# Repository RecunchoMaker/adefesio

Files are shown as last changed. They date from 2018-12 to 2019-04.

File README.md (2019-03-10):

# adefesio

**adefesio** intentará ser un pequeno robot para iniciarse na competición da resolución de
de labirintos. Está baseado en componentes de baixo custe (arduino, motores micrometal...)
e polo tanto a intención do proxecto non é facer un robot competitivo, senón explorar
e investigar os desfíos de programación que aparecen nesta competición.

## making off

En [Adefesio blog](https://recunchomaker.github.io/adefesio/) estamos facendo un
blog co progreso do proxecto.

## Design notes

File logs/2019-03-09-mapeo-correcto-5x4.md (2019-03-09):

GO!
leds:214	0	-1	289	
* accion: dist:0.09 acel= 1.00 vmax=0.20 vfin=0.20 deceleracion=1.00 pasos_hasta_dec=236 pasos_obj=236 r=99999.00
leds:249	1	0	174	
cambio a casilla 15
Orientacion 0
+-----+-----+-----+-----+
|   0     1     2     3 | 
|                       |     
+     +     +     +     +
|   5     6     7     8 | 
|                       |     
+     +     +     +     +
|  10    11    12    13 | 
|                       |     
+     +     +     +     +
|  15 |  16    17    18 | 
|   A |                 |     
+     +     +     +     +
|  20 |  21    22    23 | 
|     |                 |     
+-----+-----+-----+-----+

continuo - leds enfrente: 0/1
* accion: dist:0.18 acel= 1.00 vmax=0.20 vfin=0.20 deceleracion=1.00 pasos_hasta_dec=472 pasos_obj=472 r=99999.00
sinc pared derecha
leds:135	0	0	0	
cambio a casilla 10
Orientacion 0
+-----+-----+-----+-----+
|   0     1     2     3 | 
|                       |     
+     +     +     +     +
|   5     6     7     8 | 
|                       |     
+     +     +     +     +
|  10    11    12    13 | 
|   A                   |     
+     +     +     +     +
|  15 |  16    17    18 | 
|     |                 |     
+     +     +     +     +
|  20 |  21    22    23 | 
|     |                 |     
+-----+-----+-----+-----+

continuo - leds enfrente: 0/0
pp giro derecha
* accion: dist:0.09 acel= 1.00 vmax=0.20 vfin=0.10 deceleracion=0.80 pasos_hasta_dec=186 pasos_obj=236 r=99999.00
pausa pregiro
* accion: dist:0.00 acel= 0.00 vmax=0.00 vfin=0.00 deceleracion=0.00 pasos_hasta_dec=-2147483648 pasos_obj=0 r=0.20
leds:112	1	1	1	
giro derecha
* accion: dist:0.05 acel= 1.00 vmax=0.20 vfin=0.10 deceleracion=1.00 pasos_hasta_dec=92 pasos_obj=131 r=0.01
pausa inicial
* accion: dist:0.00 acel= 0.00 vmax=0.00 vfin=0.00 deceleracion=0.00 pasos_hasta_dec=-2147483648 pasos_obj=0 r=0.20
Orientacion 1
+-----+-----+-----+-----+
|   0     1     2     3 | 
|                       |     
+     +     +     +     +
|   5     6     7     8 | 
|                       |     
+     +     +     +     +
|  10    11    12    13 | 
|   >                   |     
+     +     +     +     +
|  15 |  16    17    18 | 
|     |                 |     
+     +     +     +     +
|  20 |  21    22    23 | 
|     |                 |     
+-----+-----+-----+-----+

* accion: dist:0.09 acel= 1.00 vmax=0.20 vfin=0.20 deceleracion=1.00 pasos_hasta_dec=236 pasos_obj=236 r=99999.00
leds:160	0	0	222	
cambio a casilla 11
Orientacion 1
+-----+-----+-----+-----+
|   0     1     2     3 | 
|                       |     
+     +     +     +     +
|   5     6     7     8 | 
|                       |     
+     +-----+     +     +
|  10    11    12    13 | 
|         >             |     
+     +-----+     +     +
|  15 |  16    17    18 | 
|     |                 |     
+     +     +     +     +
|  20 |  21    22    23 | 
|     |                 |     
+-----+-----+-----+-----+

continuo - leds enfrente: 0/0
* accion: dist:0.18 acel= 1.00 vmax=0.20 vfin=0.20 deceleracion=1.00 pasos_hasta_dec=472 pasos_obj=472 r=99999.00
sinc pared derecha
leds:134	1	1	0	
cambio a casilla 12
Orientacion 1
+-----+-----+-----+-----+
|   0     1     2     3 | 
|                       |     
+     +     +     +     +
|   5     6     7     8 | 
|                       |     
+     +-----+-----+     +
|  10    11    12    13 | 
|               >       |     
+     +-----+     +     +
|  15 |  16    17    18 | 
|     |                 |     
+     +     +     +     +
|  20 |  21    22    23 | 
|     |                 |     
+-----+-----+-----+-----+

continuo - leds enfrente: 1/1
pp giro derecha
* accion: dist:0.09 acel= 1.00 vmax=0.20 vfin=0.10 deceleracion=0.80 pasos_hasta_dec=186 pasos_obj=236 r=99999.00
pausa pregiro
* accion: dist:0.00 acel= 0.00 vmax=0.00 vfin=0.00 deceleracion=0.00 pasos_hasta_dec=-2147483648 pasos_obj=0 r=0.20
leds:138	5	3	2	
giro derecha
* accion: dist:0.05 acel= 1.00 vmax=0.20 vfin=0.10 deceleracion=1.00 pasos_hasta_dec=92 pasos_obj=131 r=0.01
pausa inicial
* accion: dist:0.00 acel= 0.00 vmax=0.00 vfin=0.00 deceleracion=0.00 pasos_hasta_dec=-2147483648 pasos_obj=0 r=0.20
Orientacion 2
+-----+-----+-----+-----+
|   0     1     2     3 | 
|                       |     
+     +     +     +     +
|   5     6     7     8 | 
|                       |     
+     +-----+-----+     +
|  10    11    12    13 | 
|               V       |     
+     +-----+     +     +
|  15 |  16    17    18 | 
|     |                 |     
+     +     +     +     +
|  20 |  21    22    23 | 
|     |                 |     
+-----+-----+-----+-----+

* accion: dist:0.09 acel= 1.00 vmax=0.20 vfin=0.20 deceleracion=1.00 pasos_hasta_dec=236 pasos_obj=236 r=99999.00
leds:212	1	1	247	
cambio a casilla 17
Orientacion 2
+-----+-----+-----+-----+
|   0     1     2     3 | 
|                       |     
+     +     +     +     +
|   5     6     7     8 | 
|                       |     
+     +-----+-----+     +
|  10    11    12    13 | 
|                       |     
+     +-----+     +     +
|  15 |  16 |  17 |  18 | 
|     |     |   V |     |     
+     +     +     +     +
|  20 |  21    22    23 | 
|     |                 |     
+-----+-----+-----+-----+

continuo - leds enfrente: 1/1
* accion: dist:0.18 acel= 1.00 vmax=0.20 vfin=0.20 deceleracion=1.00 pasos_hasta_dec=472 pasos_obj=472 r=99999.00
sinc pared derecha
leds:1	41	18	0	
cambio a casilla 22
Orientacion 2
+-----+-----+-----+-----+
|   0     1     2     3 | 
|                       |     
+     +     +     +     +
|   5     6     7     8 | 
|                       |     
+     +-----+-----+     +
|  10    11    12    13 | 
|                       |     
+     +-----+     +     +
|  15 |  16 |  17 |  18 | 
|     |     |     |     |     
+     +     +     +     +
|  20 |  21    22    23 | 
|     |         V       |     
+-----+-----+-----+-----+

continuo - leds enfrente: 18/41
pp giro derecha
* accion: dist:0.09 acel= 1.00 vmax=0.20 vfin=0.10 deceleracion=0.80 pasos_hasta_dec=186 pasos_obj=236 r=99999.00
chocamos! leds:
238/377, pasos objetivo =236 recorridos =186
pausa pregiro
* accion: dist:0.00 acel= 0.00 vmax=0.00 vfin=0.00 deceleracion=0.00 pasos_hasta_dec=-2147483648 pasos_obj=0 r=0.20
leds:1	377	238	1	
giro derecha
* accion: dist:0.05 acel= 1.00 vmax=0.20 vfin=0.10 deceleracion=1.00 pasos_hasta_dec=92 pasos_obj=131 r=0.01
pausa inicial
* accion: dist:0.00 acel= 0.00 vmax=0.00 vfin=0.00 deceleracion=0.00 pasos_hasta_dec=-2147483648 pasos_obj=0 r=0.20
Orientacion 3
+-----+-----+-----+-----+
|   0     1     2     3 | 
|                       |     
+     +     +     +     +
|   5     6     7     8 | 
|                       |     
+     +-----+-----+     +
|  10    11    12    13 | 
|                       |     
+     +-----+     +     +
|  15 |  16 |  17 |  18 | 
|     |     |     |     |     
+     +     +     +     +
|  20 |  21    22    23 | 
|     |         <       |     
+-----+-----+-----+-----+

* accion: dist:0.09 acel= 1.00 vmax=0.20 vfin=0.20 deceleracion=1.00 pasos_hasta_dec=236 pasos_obj=236 r=99999.00
leds:109	40	12	1	
cambio a casilla 21
Orientacion 3
+-----+-----+-----+-----+
|   0     1     2     3 | 
|                       |     
+     +     +     +     +
|   5     6     7     8 | 
|                       |     
+     +-----+-----+     +
|  10    11    12    13 | 
|                       |     
+     +-----+     +     +
|  15 |  16 |  17 |  18 | 
|     |     |     |     |     
+     +     +     +     +
|  20 |  21    22    23 | 
|     |   <             |     
+-----+-----+-----+-----+

continuo - leds enfrente: 12/40
pp giro derecha
* accion: dist:0.09 acel= 1.00 vmax=0.20 vfin=0.10 deceleracion=0.80 pasos_hasta_dec=186 pasos_obj=236 r=99999.00
chocamos! leds:
236/379, pasos objetivo =236 recorridos =190
pausa pregiro
* accion: dist:0.00 acel= 0.00 vmax=0.00 vfin=0.00 deceleracion=0.00 pasos_hasta_dec=-2147483648 pasos_obj=0 r=0.20
leds:100	379	236	1	
giro derecha
* accion: dist:0.05 acel= 1.00 vmax=0.20 vfin=0.10 deceleracion=1.00 pasos_hasta_dec=92 pasos_obj=131 r=0.01
pausa inicial
* accion: dist:0.00 acel= 0.00 vmax=0.00 vfin=0.00 deceleracion=0.00 pasos_hasta_dec=-2147483648 pasos_obj=0 r=0.20
Orientacion 0
+-----+-----+-----+-----+
|   0     1     2     3 | 
|                       |     
+     +     +     +     +
|   5     6     7     8 | 
|                       |     
+     +-----+-----+     +
|  10    11    12    13 | 
|                       |     
+     +-----+     +     +
|  15 |  16 |  17 |  18 | 
|     |     |     |     |     
+     +     +     +     +
|  20 |  21    22    23 | 
|     |   A             |     
+-----+-----+-----+-----+

* accion: dist:0.09 acel= 1.00 vmax=0.20 vfin=0.20 deceleracion=1.00 pasos_hasta_dec=236 pasos_obj=236 r=99999.00
leds:194	93	60	267	
cambio a casilla 16
Orientacion 0
+-----+-----+-----+-----+
|   0     1     2     3 | 
|                       |     
+     +     +     +     +
|   5     6     7     8 | 
|                       |     
+     +-----+-----+     +
|  10    11    12    13 | 
|                       |     
+     +-----+     +     +
|  15 |  16 |  17 |  18 | 
|     |   A |     |     |     
+     +     +     +     +
|  20 |  21    22    23 | 
|     |                 |     
+-----+-----+-----+-----+

continuo - leds enfrente: 60/93
callejon sin salida - paro para giro 180
* accion: dist:0.09 acel= 1.00 vmax=0.20 vfin=0.10 deceleracion=0.80 pasos_hasta_dec=186 pasos_obj=236 r=99999.00
chocamos! leds:
276/329, pasos objetivo =236 recorridos =107
pausa pregiro
* accion: dist:0.00 acel= 0.00 vmax=0.00 vfin=0.00 deceleracion=0.00 pasos_hasta_dec=-2147483648 pasos_obj=0 r=0.20
leds:224	329	276	229	
giro 180
* accion: dist:0.10 acel= 1.00 vmax=0.20 vfin=0.10 deceleracion=1.00 pasos_hasta_dec=223 pasos_obj=262 r=0.00
pausa inicial
* accion: dist:0.00 acel= 0.00 vmax=0.00 vfin=0.00 deceleracion=0.00 pasos_hasta_dec=-2147483648 pasos_obj=0 r=0.20
Orientacion 2
+-----+-----+-----+-----+
|   0     1     2     3 | 
|                       |     
+     +     +     +     +
|   5     6     7     8 | 
|                       |     
+     +-----+-----+     +
|  10    11    12    13 | 
|                       |     
+     +-----+     +     +
|  15 |  16 |  17 |  18 | 
|     |   V |     |     |     
+     +     +     +     +
|  20 |  21    22    23 | 
|     |                 |     
+-----+-----+-----+-----+

* accion: dist:0.09 acel= 1.00 vmax=0.20 vfin=0.20 deceleracion=1.00 pasos_hasta_dec=236 pasos_obj=236 r=99999.00
leds:0	40	26	158	
cambio a casilla 21
Orientacion 2
+-----+-----+-----+-----+
|   0     1     2     3 | 
|                       |     
+     +     +     +     +
|   5     6     7     8 | 
|                       |     
+     +-----+-----+     +
|  10    11    12    13 | 
|                       |     
+     +-----+     +     +
|  15 |  16 |  17 |  18 | 
|     |     |     |     |     
+     +     +     +     +
|  20 |  21    22    23 | 
|     |   V             |     
+-----+-----+-----+-----+

continuo - leds enfrente: 26/40
paro para giro izquierda
* accion: dist:0.09 acel= 1.00 vmax=0.20 vfin=0.10 deceleracion=0.80 pasos_hasta_dec=186 pasos_obj=236 r=99999.00
chocamos! leds:
259/355, pasos objetivo =236 recorridos =178
pausa pregiro
* accion: dist:0.00 acel= 0.00 vmax=0.00 vfin=0.00 deceleracion=0.00 pasos_hasta_dec=-2147483648 pasos_obj=0 r=0.20
leds:0	355	259	143	
giro izquierda
* accion: dist:0.05 acel= 1.00 vmax=0.20 vfin=0.10 deceleracion=1.00 pasos_hasta_dec=92 pasos_obj=131 r=0.00
pausa inicial
* accion: dist:0.00 acel= 0.00 vmax=0.00 vfin=0.00 deceleracion=0.00 pasos_hasta_dec=-2147483648 pasos_obj=0 r=0.20
Orientacion 1
+-----+-----+-----+-----+
|   0     1     2     3 | 
|                       |     
+     +     +     +     +
|   5     6     7     8 | 
|                       |     
+     +-----+-----+     +
|  10    11    12    13 | 
|                       |     
+     +-----+     +     +
|  15 |  16 |  17 |  18 | 
|     |     |     |     |     
+     +     +     +     +
|  20 |  21    22    23 | 
|     |   >             |     
+-----+-----+-----+-----+

* accion: dist:0.09 acel= 1.00 vmax=0.20 vfin=0.20 deceleracion=1.00 pasos_hasta_dec=236 pasos_obj=236 r=99999.00
leds:1	5	1	95	
cambio a casilla 22
Orientacion 1
+-----+-----+-----+-----+
|   0     1     2     3 | 
|                       |     
+     +     +     +     +
|   5     6     7     8 | 
|                       |     
+     +-----+-----+     +
|  10    11    12    13 | 
|                       |     
+     +-----+     +     +
|  15 |  16 |  17 |  18 | 
|     |     |     |     |     
+     +     +     +     +
|  20 |  21    22    23 | 
|     |         >       |     
+-----+-----+-----+-----+

continuo - leds enfrente: 1/5
* accion: dist:0.18 acel= 1.00 vmax=0.20 vfin=0.20 deceleracion=1.00 pasos_hasta_dec=472 pasos_obj=472 r=99999.00
leds:248	63	21	204	
cambio a casilla 23
Orientacion 1
+-----+-----+-----+-----+
|   0     1     2     3 | 
|                       |     
+     +     +     +     +
|   5     6     7     8 | 
|                       |     
+     +-----+-----+     +
|  10    11    12    13 | 
|                       |     
+     +-----+     +     +
|  15 |  16 |  17 |  18 | 
|     |     |     |     |     
+     +     +     +-----+
|  20 |  21    22    23 | 
|     |               > |     
+-----+-----+-----+-----+

continuo - leds enfrente: 21/63
callejon sin salida - paro para giro 180
* accion: dist:0.09 acel= 1.00 vmax=0.20 vfin=0.10 deceleracion=0.80 pasos_hasta_dec=186 pasos_obj=236 r=99999.00
chocamos! leds:
213/390, pasos objetivo =236 recorridos =166
pausa pregiro
* accion: dist:0.00 acel= 0.00 vmax=0.00 vfin=0.00 deceleracion=0.00 pasos_hasta_dec=-2147483648 pasos_obj=0 r=0.20
leds:226	390	213	309	
giro 180
* accion: dist:0.10 acel= 1.00 vmax=0.20 vfin=0.10 deceleracion=1.00 pasos_hasta_dec=223 pasos_obj=262 r=0.00
pausa inicial
* accion: dist:0.00 acel= 0.00 vmax=0.00 vfin=0.00 deceleracion=0.00 pasos_hasta_dec=-2147483648 pasos_obj=0 r=0.20
Orientacion 3
+-----+-----+-----+-----+
|   0     1     2     3 | 
|                       |     
+     +     +     +     +
|   5     6     7     8 | 
|                       |     
+     +-----+-----+     +
|  10    11    12    13 | 
|                       |     
+     +-----+     +     +
|  15 |  16 |  17 |  18 | 
|     |     |     |     |     
+     +     +     +-----+
|  20 |  21    22    23 | 
|     |               < |     
+-----+-----+-----+-----+

* accion: dist:0.09 acel= 1.00 vmax=0.20 vfin=0.20 deceleracion=1.00 pasos_hasta_dec=236 pasos_obj=236 r=99999.00
leds:152	1	1	0	
cambio a casilla 22
Orientacion 3
+-----+-----+-----+-----+
|   0     1     2     3 | 
|                       |     
+     +     +     +     +
|   5     6     7     8 | 
|                       |     
+     +-----+-----+     +
|  10    11    12    13 | 
|                       |     
+     +-----+     +     +
|  15 |  16 |  17 |  18 | 
|     |     |     |     |     
+     +     +     +-----+
|  20 |  21    22    23 | 
|     |         <       |     
+-----+-----+-----+-----+

continuo - leds enfrente: 1/1
pp giro derecha
* accion: dist:0.09 acel= 1.00 vmax=0.20 vfin=0.10 deceleracion=0.80 pasos_hasta_dec=186 pasos_obj=236 r=99999.00
pausa pregiro
* accion: dist:0.00 acel= 0.00 vmax=0.00 vfin=0.00 deceleracion=0.00 pasos_hasta_dec=-2147483648 pasos_obj=0 r=0.20
leds:115	3	3	1	
giro derecha
* accion: dist:0.05 acel= 1.00 vmax=0.20 vfin=0.10 deceleracion=1.00 pasos_hasta_dec=92 pasos_obj=131 r=0.01
pausa inicial
* accion: dist:0.00 acel= 0.00 vmax=0.00 vfin=0.00 deceleracion=0.00 pasos_hasta_dec=-2147483648 pasos_obj=0 r=0.20
Orientacion 0
+-----+-----+-----+-----+
|   0     1     2     3 | 
|                       |     
+     +     +     +     +
|   5     6     7     8 | 
|                       |     
+     +-----+-----+     +
|  10    11    12    13 | 
|                       |     
+     +-----+     +     +
|  15 |  16 |  17 |  18 | 
|     |     |     |     |     
+     +     +     +-----+
|  20 |  21    22    23 | 
|     |         A       |     
+-----+-----+-----+-----+

* accion: dist:0.09 acel= 1.00 vmax=0.20 vfin=0.20 deceleracion=1.00 pasos_hasta_dec=236 pasos_obj=236 r=99999.00
leds:210	1	0	266	
cambio a casilla 17
Orientacion 0
+-----+-----+-----+-----+
|   0     1     2     3 | 
|                       |     
+     +     +     +     +
|   5     6     7     8 | 
|                       |     
+     +-----+-----+     +
|  10    11    12    13 | 
|                       |     
+     +-----+     +     +
|  15 |  16 |  17 |  18 | 
|     |     |   A |     |     
+     +     +     +-----+
|  20 |  21    22    23 | 
|     |                 |     
+-----+-----+-----+-----+

continuo - leds enfrente: 0/1
* accion: dist:0.18 acel= 1.00 vmax=0.20 vfin=0.20 deceleracion=1.00 pasos_hasta_dec=472 pasos_obj=472 r=99999.00
sinc pared derecha
leds:0	22	13	1	
cambio a casilla 12
Orientacion 0
+-----+-----+-----+-----+
|   0     1     2     3 | 
|                       |     
+     +     +     +     +
|   5     6     7     8 | 
|                       |     
+     +-----+-----+     +
|  10    11    12    13 | 
|               A       |     
+     +-----+     +     +
|  15 |  16 |  17 |  18 | 
|     |     |     |     |     
+     +     +     +-----+
|  20 |  21    22    23 | 
|     |                 |     
+-----+-----+-----+-----+

continuo - leds enfrente: 13/22
pp giro derecha
* accion: dist:0.09 acel= 1.00 vmax=0.20 vfin=0.10 deceleracion=0.80 pasos_hasta_dec=186 pasos_obj=236 r=99999.00
chocamos! leds:
247/358, pasos objetivo =236 recorridos =206
pausa pregiro
* accion: dist:0.00 acel= 0.00 vmax=0.00 vfin=0.00 deceleracion=0.00 pasos_hasta_dec=-2147483648 pasos_obj=0 r=0.20
leds:-1	358	247	1	
giro derecha
* accion: dist:0.05 acel= 1.00 vmax=0.20 vfin=0.10 deceleracion=1.00 pasos_hasta_dec=92 pasos_obj=131 r=0.01
pausa inicial
* accion: dist:0.00 acel= 0.00 vmax=0.00 vfin=0.00 deceleracion=0.00 pasos_hasta_dec=-2147483648 pasos_obj=0 r=0.20
Orientacion 1
+-----+-----+-----+-----+
|   0     1     2     3 | 
|                       |     
+     +     +     +     +
|   5     6     7     8 | 
|                       |     
+     +-----+-----+     +
|  10    11    12    13 | 
|               >       |     
+     +-----+     +     +
|  15 |  16 |  17 |  18 | 
|     |     |     |     |     
+     +     +     +-----+
|  20 |  21    22    23 | 
|     |                 |     
+-----+-----+-----+-----+

* accion: dist:0.09 acel= 1.00 vmax=0.20 vfin=0.20 deceleracion=1.00 pasos_hasta_dec=236 pasos_obj=236 r=99999.00
leds:1	57	20	1	
cambio a casilla 13
Orientacion 1
+-----+-----+-----+-----+
|   0     1     2     3 | 
|                       |     
+     +     +     +     +
|   5     6     7     8 | 
|                       |     
+     +-----+-----+     +
|  10    11    12    13 | 
|                     > |     
+     +-----+     +     +
|  15 |  16 |  17 |  18 | 
|     |     |     |     |     
+     +     +     +-----+
|  20 |  21    22    23 | 
|     |                 |     
+-----+-----+-----+-----+

continuo - leds enfrente: 20/57
pp giro derecha
* accion: dist:0.09 acel= 1.00 vmax=0.20 vfin=0.10 deceleracion=0.80 pasos_hasta_dec=186 pasos_obj=236 r=99999.00
chocamos! leds:
197/410, pasos objetivo =236 recorridos =153
pausa pregiro
* accion: dist:0.00 acel= 0.00 vmax=0.00 vfin=0.00 deceleracion=0.00 pasos_hasta_dec=-2147483648 pasos_obj=0 r=0.20
leds:1	410	197	1	
giro derecha
* accion: dist:0.05 acel= 1.00 vmax=0.20 vfin=0.10 deceleracion=1.00 pasos_hasta_dec=92 pasos_obj=131 r=0.01
pausa inicial
* accion: dist:0.00 acel= 0.00 vmax=0.00 vfin=0.00 deceleracion=0.00 pasos_hasta_dec=-2147483648 pasos_obj=0 r=0.20
Orientacion 2
+-----+-----+-----+-----+
|   0     1     2     3 | 
|                       |     
+     +     +     +     +
|   5     6     7     8 | 
|                       |     
+     +-----+-----+     +
|  10    11    12    13 | 
|                     V |     
+     +-----+     +     +
|  15 |  16 |  17 |  18 | 
|     |     |     |     |     
+     +     +     +-----+
|  20 |  21    22    23 | 
|     |                 |     
+-----+-----+-----+-----+

* accion: dist:0.09 acel= 1.00 vmax=0.20 vfin=0.20 deceleracion=1.00 pasos_hasta_dec=236 pasos_obj=236 r=99999.00
leds:174	50	37	209	
cambio a casilla 18
Orientacion 2
+-----+-----+-----+-----+
|   0     1     2     3 | 
|                       |     
+     +     +     +     +
|   5     6     7     8 | 
|                       |     
+     +-----+-----+     +
|  10    11    12    13 | 
|                       |     
+     +-----+     +     +
|  15 |  16 |  17 |  18 | 
|     |     |     |   V |     
+     +     +     +-----+
|  20 |  21    22    23 | 
|     |                 |     
+-----+-----+-----+-----+

continuo - leds enfrente: 37/50
callejon sin salida - paro para giro 180
* accion: dist:0.09 acel= 1.00 vmax=0.20 vfin=0.10 deceleracion=0.80 pasos_hasta_dec=186 pasos_obj=236 r=99999.00
chocamos! leds:
307/306, pasos objetivo =236 recorridos =147
pausa pregiro
* accion: dist:0.00 acel= 0.00 vmax=0.00 vfin=0.00 deceleracion=0.00 pasos_hasta_dec=-2147483648 pasos_obj=0 r=0.20
leds:252	306	307	204	
giro 180
* accion: dist:0.10 acel= 1.00 vmax=0.20 vfin=0.10 deceleracion=1.00 pasos_hasta_dec=223 pasos_obj=262 r=0.00
pausa inicial
* accion: dist:0.00 acel= 0.00 vmax=0.00 vfin=0.00 deceleracion=0.00 pasos_hasta_dec=-2147483648 pasos_obj=0 r=0.20
Orientacion 0
+-----+-----+-----+-----+
|   0     1     2     3 | 
|                       |     
+     +     +     +     +
|   5     6     7     8 | 
|                       |     
+     +-----+-----+     +
|  10    11    12    13 | 
|                       |     
+     +-----+     +     +
|  15 |  16 |  17 |  18 | 
|     |     |     |   A |     
+     +     +     +-----+
|  20 |  21    22    23 | 
|     |                 |     
+-----+-----+-----+-----+

* accion: dist:0.09 acel= 1.00 vmax=0.20 vfin=0.20 deceleracion=1.00 pasos_hasta_dec=236 pasos_obj=236 r=99999.00
leds:0	1	0	216	
cambio a casilla 13
Orientacion 0
+-----+-----+-----+-----+
|   0     1     2     3 | 
|                       |     
+     +     +     +     +
|   5     6     7     8 | 
|                       |     
+     +-----+-----+     +
|  10    11    12    13 | 
|                     A |     
+     +-----+     +     +
|  15 |  16 |  17 |  18 | 
|     |     |     |     |     
+     +     +     +-----+
|  20 |  21    22    23 | 
|     |                 |     
+-----+-----+-----+-----+

continuo - leds enfrente: 0/1
* accion: dist:0.18 acel= 1.00 vmax=0.20 vfin=0.20 deceleracion=1.00 pasos_hasta_dec=472 pasos_obj=472 r=99999.00
leds:1	5	13	106	
cambio a casilla 8
Orientacion 0
+-----+-----+-----+-----+
|   0     1     2     3 | 
|                       |     
+     +     +     +     +
|   5     6     7     8 | 
|                     A |     
+     +-----+-----+     +
|  10    11    12    13 | 
|                       |     
+     +-----+     +     +
|  15 |  16 |  17 |  18 | 
|     |     |     |     |     
+     +     +     +-----+
|  20 |  21    22    23 | 
|     |                 |     
+-----+-----+-----+-----+

continuo - leds enfrente: 13/5
paro para giro izquierda
* accion: dist:0.09 acel= 1.00 vmax=0.20 vfin=0.10 deceleracion=0.80 pasos_hasta_dec=186 pasos_obj=236 r=99999.00
chocamos! leds:
248/356, pasos objetivo =236 recorridos =227
pausa pregiro
* accion: dist:0.00 acel= 0.00 vmax=0.00 vfin=0.00 deceleracion=0.00 pasos_hasta_dec=-2147483648 pasos_obj=0 r=0.20
leds:2	356	248	144	
giro izquierda
* accion: dist:0.05 acel= 1.00 vmax=0.20 vfin=0.10 deceleracion=1.00 pasos_hasta_dec=92 pasos_obj=131 r=0.00
pausa inicial
* accion: dist:0.00 acel= 0.00 vmax=0.00 vfin=0.00 deceleracion=0.00 pasos_hasta_dec=-2147483648 pasos_obj=0 r=0.20
Orientacion 3
+-----+-----+-----+-----+
|   0     1     2     3 | 
|                       |     
+     +     +     +-----+
|   5     6     7     8 | 
|                     < |     
+     +-----+-----+     +
|  10    11    12    13 | 
|                       |     
+     +-----+     +     +
|  15 |  16 |  17 |  18 | 
|     |     |     |     |     
+     +     +     +-----+
|  20 |  21    22    23 | 
|     |                 |     
+-----+-----+-----+-----+

* accion: dist:0.09 acel= 1.00 vmax=0.20 vfin=0.20 deceleracion=1.00 pasos_hasta_dec=236 pasos_obj=236 r=99999.00
leds:178	61	25	1	
cambio a casilla 7
Orientacion 3
+-----+-----+-----+-----+
|   0     1     2     3 | 
|                       |     
+     +     +     +-----+
|   5     6     7     8 | 
|               <       |     
+     +-----+-----+     +
|  10    11    12    13 | 
|                       |     
+     +-----+     +     +
|  15 |  16 |  17 |  18 | 
|     |     |     |     |     
+     +     +     +-----+
|  20 |  21    22    23 | 
|     |                 |     
+-----+-----+-----+-----+

continuo - leds enfrente: 25/61
pp giro derecha
* accion: dist:0.09 acel= 1.00 vmax=0.20 vfin=0.10 deceleracion=0.80 pasos_hasta_dec=186 pasos_obj=236 r=99999.00
chocamos! leds:
200/409, pasos objetivo =236 recorridos =151
pausa pregiro
* accion: dist:0.00 acel= 0.00 vmax=0.00 vfin=0.00 deceleracion=0.00 pasos_hasta_dec=-2147483648 pasos_obj=0 r=0.20
leds:150	409	200	2	
giro derecha
* accion: dist:0.05 acel= 1.00 vmax=0.20 vfin=0.10 deceleracion=1.00 pasos_hasta_dec=92 pasos_obj=131 r=0.01
pausa inicial
* accion: dist:0.00 acel= 0.00 vmax=0.00 vfin=0.00 deceleracion=0.00 pasos_hasta_dec=-2147483648 pasos_obj=0 r=0.20
Orientacion 0
+-----+-----+-----+-----+
|   0     1     2     3 | 
|                       |     
+     +     +     +-----+
|   5     6 |   7     8 | 
|           |   A       |     
+     +-----+-----+     +
|  10    11    12    13 | 
|                       |     
+     +-----+     +     +
|  15 |  16 |  17 |  18 | 
|     |     |     |     |     
+     +     +     +-----+
|  20 |  21    22    23 | 
|     |                 |     
+-----+-----+-----+-----+

* accion: dist:0.09 acel= 1.00 vmax=0.20 vfin=0.20 deceleracion=1.00 pasos_hasta_dec=236 pasos_obj=236 r=99999.00
leds:88	64	23	1	
cambio a casilla 2
Orientacion 0
+-----+-----+-----+-----+
|   0     1 |   2     3 | 
|           |   A       |     
+     +     +     +-----+
|   5     6 |   7     8 | 
|           |           |     
+     +-----+-----+     +
|  10    11    12    13 | 
|                       |     
+     +-----+     +     +
|  15 |  16 |  17 |  18 | 
|     |     |     |     |     
+     +     +     +-----+
|  20 |  21    22    23 | 
|     |                 |     
+-----+-----+-----+-----+

continuo - leds enfrente: 23/64
pp giro derecha
* accion: dist:0.09 acel= 1.00 vmax=0.20 vfin=0.10 deceleracion=0.80 pasos_hasta_dec=186 pasos_obj=236 r=99999.00
chocamos! leds:
232/378, pasos objetivo =236 recorridos =151
pausa pregiro
* accion: dist:0.00 acel= 0.00 vmax=0.00 vfin=0.00 deceleracion=0.00 pasos_hasta_dec=-2147483648 pasos_obj=0 r=0.20
leds:100	378	232	1	
giro derecha
* accion: dist:0.05 acel= 1.00 vmax=0.20 vfin=0.10 deceleracion=1.00 pasos_hasta_dec=92 pasos_obj=131 r=0.01
pausa inicial
* accion: dist:0.00 acel= 0.00 vmax=0.00 vfin=0.00 deceleracion=0.00 pasos_hasta_dec=-2147483648 pasos_obj=0 r=0.20
Orientacion 1
+-----+-----+-----+-----+
|   0     1 |   2     3 | 
|           |   >       |     
+     +     +     +-----+
|   5     6 |   7     8 | 
|           |           |     
+     +-----+-----+     +
|  10    11    12    13 | 
|                       |     
+     +-----+     +     +
|  15 |  16 |  17 |  18 | 
|     |     |     |     |     
+     +     +     +-----+
|  20 |  21    22    23 | 
|     |                 |     
+-----+-----+-----+-----+

* accion: dist:0.09 acel= 1.00 vmax=0.20 vfin=0.20 deceleracion=1.00 pasos_hasta_dec=236 pasos_obj=236 r=99999.00
leds:257	41	35	239	
cambio a casilla 3
Orientacion 1
+-----+-----+-----+-----+
|   0     1 |   2     3 | 
|           |         > |     
+     +     +     +-----+
|   5     6 |   7     8 | 
|           |           |     
+     +-----+-----+     +
|  10    11    12    13 | 
|                       |     
+     +-----+     +     +
|  15 |  16 |  17 |  18 | 
|     |     |     |     |     
+     +     +     +-----+
|  20 |  21    22    23 | 
|     |                 |     
+-----+-----+-----+-----+

continuo - leds enfrente: 35/41
callejon sin salida - paro para giro 180
* accion: dist:0.09 acel= 1.00 vmax=0.20 vfin=0.10 deceleracion=0.80 pasos_hasta_dec=186 pasos_obj=236 r=99999.00
chocamos! leds:
284/318, pasos objetivo =236 recorridos =161
pausa pregiro
* accion: dist:0.00 acel= 0.00 vmax=0.00 vfin=0.00 deceleracion=0.00 pasos_hasta_dec=-2147483648 pasos_obj=0 r=0.20
leds:306	318	284	245	
giro 180
* accion: dist:0.10 acel= 1.00 vmax=0.20 vfin=0.10 deceleracion=1.00 pasos_hasta_dec=223 pasos_obj=262 r=0.00
pausa inicial
* accion: dist:0.00 acel= 0.00 vmax=0.00 vfin=0.00 deceleracion=0.00 pasos_hasta_dec=-2147483648 pasos_obj=0 r=0.20
Orientacion 3
+-----+-----+-----+-----+
|   0     1 |   2     3 | 
|           |         < |     
+     +     +     +-----+
|   5     6 |   7     8 | 
|           |           |     
+     +-----+-----+     +
|  10    11    12    13 | 
|                       |     
+     +-----+     +     +
|  15 |  16 |  17 |  18 | 
|     |     |     |     |     
+     +     +     +-----+
|  20 |  21    22    23 | 
|     |                 |     
+-----+-----+-----+-----+

* accion: dist:0.09 acel= 1.00 vmax=0.20 vfin=0.20 deceleracion=1.00 pasos_hasta_dec=236 pasos_obj=236 r=99999.00
leds:0	12	13	215	
cambio a casilla 2
Orientacion 3
+-----+-----+-----+-----+
|   0     1 |   2     3 | 
|           |   <       |     
+     +     +     +-----+
|   5     6 |   7     8 | 
|           |           |     
+     +-----+-----+     +
|  10    11    12    13 | 
|                       |     
+     +-----+     +     +
|  15 |  16 |  17 |  18 | 
|     |     |     |     |     
+     +     +     +-----+
|  20 |  21    22    23 | 
|     |                 |     
+-----+-----+-----+-----+

continuo - leds enfrente: 13/12
paro para giro izquierda
* accion: dist:0.09 acel= 1.00 vmax=0.20 vfin=0.10 deceleracion=0.80 pasos_hasta_dec=186 pasos_obj=236 r=99999.00
pausa pregiro
* accion: dist:0.00 acel= 0.00 vmax=0.00 vfin=0.00 deceleracion=0.00 pasos_hasta_dec=-2147483648 pasos_obj=0 r=0.20
leds:1	252	250	146	
giro izquierda
* accion: dist:0.05 acel= 1.00 vmax=0.20 vfin=0.10 deceleracion=1.00 pasos_hasta_dec=92 pasos_obj=131 r=0.00
pausa inicial
* accion: dist:0.00 acel= 0.00 vmax=0.00 vfin=0.00 deceleracion=0.00 pasos_hasta_dec=-2147483648 pasos_obj=0 r=0.20
Orientacion 2
+-----+-----+-----+-----+
|   0     1 |   2     3 | 
|           |   V       |     
+     +     +     +-----+
|   5     6 |   7     8 | 
|           |           |     
+     +-----+-----+     +
|  10    11    12    13 | 
|                       |     
+     +-----+     +     +
|  15 |  16 |  17 |  18 | 
|     |     |     |     |     
+     +     +     +-----+
|  20 |  21    22    23 | 
|     |                 |     
+-----+-----+-----+-----+

* accion: dist:0.09 acel= 1.00 vmax=0.20 vfin=0.20 deceleracion=1.00 pasos_hasta_dec=236 pasos_obj=236 r=99999.00
leds:1	14	27	81	
cambio a casilla 7
Orientacion 2
+-----+-----+-----+-----+
|   0     1 |   2     3 | 
|           |           |     
+     +     +     +-----+
|   5     6 |   7     8 | 
|           |   V       |     
+     +-----+-----+     +
|  10    11    12    13 | 
|                       |     
+     +-----+     +     +
|  15 |  16 |  17 |  18 | 
|     |     |     |     |     
+     +     +     +-----+
|  20 |  21    22    23 | 
|     |                 |     
+-----+-----+-----+-----+

continuo - leds enfrente: 27/14
paro para giro izquierda
* accion: dist:0.09 acel= 1.00 vmax=0.20 vfin=0.10 deceleracion=0.80 pasos_hasta_dec=186 pasos_obj=236 r=99999.00
chocamos! leds:
277/336, pasos objetivo =236 recorridos =166
pausa pregiro
* accion: dist:0.00 acel= 0.00 vmax=0.00 vfin=0.00 deceleracion=0.00 pasos_hasta_dec=-2147483648 pasos_obj=0 r=0.20
leds:2	336	277	112	
giro izquierda
* accion: dist:0.05 acel= 1.00 vmax=0.20 vfin=0.10 deceleracion=1.00 pasos_hasta_dec=92 pasos_obj=131 r=0.00
pausa inicial
* accion: dist:0.00 acel= 0.00 vmax=0.00 vfin=0.00 deceleracion=0.00 pasos_hasta_dec=-2147483648 pasos_obj=0 r=0.20
Orientacion 1
+-----+-----+-----+-----+
|   0     1 |   2     3 | 
|           |           |     
+     +     +     +-----+
|   5     6 |   7     8 | 
|           |   >       |     
+     +-----+-----+     +
|  10    11    12    13 | 
|                       |     
+     +-----+     +     +
|  15 |  16 |  17 |  18 | 
|     |     |     |     |     
+     +     +     +-----+
|  20 |  21    22    23 | 
|     |                 |     
+-----+-----+-----+-----+

* accion: dist:0.09 acel= 1.00 vmax=0.20 vfin=0.20 deceleracion=1.00 pasos_hasta_dec=236 pasos_obj=236 r=99999.00
leds:188	68	36	0	
cambio a casilla 8
Orientacion 1
+-----+-----+-----+-----+
|   0     1 |   2     3 | 
|           |           |     
+     +     +     +-----+
|   5     6 |   7     8 | 
|           |         > |     
+     +-----+-----+     +
|  10    11    12    13 | 
|                       |     
+     +-----+     +     +
|  15 |  16 |  17 |  18 | 
|     |     |     |     |     
+     +     +     +-----+
|  20 |  21    22    23 | 
|     |                 |     
+-----+-----+-----+-----+

continuo - leds enfrente: 36/68
pp giro derecha
* accion: dist:0.09 acel= 1.00 vmax=0.20 vfin=0.10 deceleracion=0.80 pasos_hasta_dec=186 pasos_obj=236 r=99999.00
chocamos! leds:
244/366, pasos objetivo =236 recorridos =137
pausa pregiro
* accion: dist:0.00 acel= 0.00 vmax=0.00 vfin=0.00 deceleracion=0.00 pasos_hasta_dec=-2147483648 pasos_obj=0 r=0.20
leds:191	366	244	0	
giro derecha
* accion: dist:0.05 acel= 1.00 vmax=0.20 vfin=0.10 deceleracion=1.00 pasos_hasta_dec=92 pasos_obj=131 r=0.01
pausa inicial
* accion: dist:0.00 acel= 0.00 vmax=0.00 vfin=0.00 deceleracion=0.00 pasos_hasta_dec=-2147483648 pasos_obj=0 r=0.20
Orientacion 2
+-----+-----+-----+-----+
|   0     1 |   2     3 | 
|           |           |     
+     +     +     +-----+
|   5     6 |   7     8 | 
|           |         V |     
+     +-----+-----+     +
|  10    11    12    13 | 
|                       |     
+     +-----+     +     +
|  15 |  16 |  17 |  18 | 
|     |     |     |     |     
+     +     +     +-----+
|  20 |  21    22    23 | 
|     |                 |     
+-----+-----+-----+-----+

* accion: dist:0.09 acel= 1.00 vmax=0.20 vfin=0.20 deceleracion=1.00 pasos_hasta_dec=236 pasos_obj=236 r=99999.00
leds:109	1	1	0	
cambio a casilla 13
Orientacion 2
+-----+-----+-----+-----+
|   0     1 |   2     3 | 
|           |           |     
+     +     +     +-----+
|   5     6 |   7     8 | 
|           |           |     
+     +-----+-----+     +
|  10    11    12    13 | 
|                     V |     
+     +-----+     +     +
|  15 |  16 |  17 |  18 | 
|     |     |     |     |     
+     +     +     +-----+
|  20 |  21    22    23 | 
|     |                 |     
+-----+-----+-----+-----+

continuo - leds enfrente: 1/1
pp giro derecha
* accion: dist:0.09 acel= 1.00 vmax=0.20 vfin=0.10 deceleracion=0.80 pasos_hasta_dec=186 pasos_obj=236 r=99999.00
pausa pregiro
* accion: dist:0.00 acel= 0.00 vmax=0.00 vfin=0.00 deceleracion=0.00 pasos_hasta_dec=-2147483648 pasos_obj=0 r=0.20
leds:115	4	3	-1	
giro derecha
* accion: dist:0.05 acel= 1.00 vmax=0.20 vfin=0.10 deceleracion=1.00 pasos_hasta_dec=92 pasos_obj=131 r=0.01
pausa inicial
* accion: dist:0.00 acel= 0.00 vmax=0.00 vfin=0.00 deceleracion=0.00 pasos_hasta_dec=-2147483648 pasos_obj=0 r=0.20
Orientacion 3
+-----+-----+-----+-----+
|   0     1 |   2     3 | 
|           |           |     
+     +     +     +-----+
|   5     6 |   7     8 | 
|           |           |     
+     +-----+-----+     +
|  10    11    12    13 | 
|                     < |     
+     +-----+     +     +
|  15 |  16 |  17 |  18 | 
|     |     |     |     |     
+     +     +     +-----+
|  20 |  21    22    23 | 
|     |                 |     
+-----+-----+-----+-----+

* accion: dist:0.09 acel= 1.00 vmax=0.20 vfin=0.20 deceleracion=1.00 pasos_hasta_dec=236 pasos_obj=236 r=99999.00
leds:0	0	0	215	
cambio a casilla 12
Orientacion 3
+-----+-----+-----+-----+
|   0     1 |   2     3 | 
|           |           |     
+     +     +     +-----+
|   5     6 |   7     8 | 
|           |           |     
+     +-----+-----+     +
|  10    11    12    13 | 
|               <       |     
+     +-----+     +     +
|  15 |  16 |  17 |  18 | 
|     |     |     |     |     
+     +     +     +-----+
|  20 |  21    22    23 | 
|     |                 |     
+-----+-----+-----+-----+

continuo - leds enfrente: 0/0
* accion: dist:0.18 acel= 1.00 vmax=0.20 vfin=0.20 deceleracion=1.00 pasos_hasta_dec=472 pasos_obj=472 r=99999.00
leds:222	1	1	161	
cambio a casilla 11
Orientacion 3
+-----+-----+-----+-----+
|   0     1 |   2     3 | 
|           |           |     
+     +     +     +-----+
|   5     6 |   7     8 | 
|           |           |     
+     +-----+-----+     +
|  10    11    12    13 | 
|         <             |     
+     +-----+     +     +
|  15 |  16 |  17 |  18 | 
|     |     |     |     |     
+     +     +     +-----+
|  20 |  21    22    23 | 
|     |                 |     
+-----+-----+-----+-----+

continuo - leds enfrente: 1/1
* accion: dist:0.18 acel= 1.00 vmax=0.20 vfin=0.20 deceleracion=1.00 pasos_hasta_dec=472 pasos_obj=472 r=99999.00
sinc pared derecha
leds:0	37	20	0	
cambio a casilla 10
Orientacion 3
+-----+-----+-----+-----+
|   0     1 |   2     3 | 
|           |           |     
+     +     +     +-----+
|   5     6 |   7     8 | 
|           |           |     
+     +-----+-----+     +
|  10    11    12    13 | 
|   <                   |     
+     +-----+     +     +
|  15 |  16 |  17 |  18 | 
|     |     |     |     |     
+     +     +     +-----+
|  20 |  21    22    23 | 
|     |                 |     
+-----+-----+-----+-----+

continuo - leds enfrente: 20/37
pp giro derecha
* accion: dist:0.09 acel= 1.00 vmax=0.20 vfin=0.10 deceleracion=0.80 pasos_hasta_dec=186 pasos_obj=236 r=99999.00
chocamos! leds:
243/364, pasos objetivo =236 recorridos =180
pausa pregiro
* accion: dist:0.00 acel= 0.00 vmax=0.00 vfin=0.00 deceleracion=0.00 pasos_hasta_dec=-2147483648 pasos_obj=0 r=0.20
leds:0	364	243	1	
giro derecha
* accion: dist:0.05 acel= 1.00 vmax=0.20 vfin=0.10 deceleracion=1.00 pasos_hasta_dec=92 pasos_obj=131 r=0.01
pausa inicial
* accion: dist:0.00 acel= 0.00 vmax=0.00 vfin=0.00 deceleracion=0.00 pasos_hasta_dec=-2147483648 pasos_obj=0 r=0.20
Orientacion 0
+-----+-----+-----+-----+
|   0     1 |   2     3 | 
|           |           |     
+     +     +     +-----+
|   5     6 |   7     8 | 
|           |           |     
+     +-----+-----+     +
|  10    11    12    13 | 
|   A                   |     
+     +-----+     +     +
|  15 |  16 |  17 |  18 | 
|     |     |     |     |     
+     +     +     +-----+
|  20 |  21    22    23 | 
|     |                 |     
+-----+-----+-----+-----+

* accion: dist:0.09 acel= 1.00 vmax=0.20 vfin=0.20 deceleracion=1.00 pasos_hasta_dec=236 pasos_obj=236 r=99999.00
leds:167	1	1	328	
cambio a casilla 5
Orientacion 0
+-----+-----+-----+-----+
|   0     1 |   2     3 | 
|           |           |     
+     +     +     +-----+
|   5 |   6 |   7     8 | 
|   A |     |           |     
+     +-----+-----+     +
|  10    11    12    13 | 
|                       |     
+     +-----+     +     +
|  15 |  16 |  17 |  18 | 
|     |     |     |     |     
+     +     +     +-----+
|  20 |  21    22    23 | 
|     |                 |     
+-----+-----+-----+-----+

continuo - leds enfrente: 1/1
* accion: dist:0.18 acel= 1.00 vmax=0.20 vfin=0.20 deceleracion=1.00 pasos_hasta_dec=472 pasos_obj=472 r=99999.00
sinc pared derecha
leds:156	49	14	0	
cambio a casilla 0
Orientacion 0
+-----+-----+-----+-----+
|   0     1 |   2     3 | 
|   A       |           |     
+     +     +     +-----+
|   5 |   6 |   7     8 | 
|     |     |           |     
+     +-----+-----+     +
|  10    11    12    13 | 
|                       |     
+     +-----+     +     +
|  15 |  16 |  17 |  18 | 
|     |     |     |     |     
+     +     +     +-----+
|  20 |  21    22    23 | 
|     |                 |     
+-----+-----+-----+-----+

continuo - leds enfrente: 14/49
pp giro derecha
* accion: dist:0.09 acel= 1.00 vmax=0.20 vfin=0.10 deceleracion=0.80 pasos_hasta_dec=186 pasos_obj=236 r=99999.00
chocamos! leds:
199/406, pasos objetivo =236 recorridos =177
pausa pregiro
* accion: dist:0.00 acel= 0.00 vmax=0.00 vfin=0.00 deceleracion=0.00 pasos_hasta_dec=-2147483648 pasos_obj=0 r=0.20
leds:128	406	199	1	
giro derecha
* accion: dist:0.05 acel= 1.00 vmax=0.20 vfin=0.10 deceleracion=1.00 pasos_hasta_dec=92 pasos_obj=131 r=0.01
pausa inicial
* accion: dist:0.00 acel= 0.00 vmax=0.00 vfin=0.00 deceleracion=0.00 pasos_hasta_dec=-2147483648 pasos_obj=0 r=0.20
Orientacion 1
+-----+-----+-----+-----+
|   0     1 |   2     3 | 
|   >       |           |     
+     +     +     +-----+
|   5 |   6 |   7     8 | 
|     |     |           |     
+     +-----+-----+     +
|  10    11    12    13 | 
|                       |     
+     +-----+     +     +
|  15 |  16 |  17 |  18 | 
|     |     |     |     |     
+     +     +     +-----+
|  20 |  21    22    23 | 
|     |                 |     
+-----+-----+-----+-----+

* accion: dist:0.09 acel= 1.00 vmax=0.20 vfin=0.20 deceleracion=1.00 pasos_hasta_dec=236 pasos_obj=236 r=99999.00
leds:123	55	17	1	
cambio a casilla 1
Orientacion 1
+-----+-----+-----+-----+
|   0     1 |   2     3 | 
|         > |           |     
+     +     +     +-----+
|   5 |   6 |   7     8 | 
|     |     |           |     
+     +-----+-----+     +
|  10    11    12    13 | 
|                       |     
+     +-----+     +     +
|  15 |  16 |  17 |  18 | 
|     |     |     |     |     
+     +     +     +-----+
|  20 |  21    22    23 | 
|     |                 |     
+-----+-----+-----+-----+

continuo - leds enfrente: 17/55
pp giro derecha
* accion: dist:0.09 acel= 1.00 vmax=0.20 vfin=0.10 deceleracion=0.80 pasos_hasta_dec=186 pasos_obj=236 r=99999.00
chocamos! leds:
205/401, pasos objetivo =236 recorridos =164
pausa pregiro
* accion: dist:0.00 acel= 0.00 vmax=0.00 vfin=0.00 deceleracion=0.00 pasos_hasta_dec=-2147483648 pasos_obj=0 r=0.20
leds:106	401	205	1	
giro derecha
* accion: dist:0.05 acel= 1.00 vmax=0.20 vfin=0.10 deceleracion=1.00 pasos_hasta_dec=92 pasos_obj=131 r=0.01
pausa inicial
* accion: dist:0.00 acel= 0.00 vmax=0.00 vfin=0.00 deceleracion=0.00 pasos_hasta_dec=-2147483648 pasos_obj=0 r=0.20
Orientacion 2
+-----+-----+-----+-----+
|   0     1 |   2     3 | 
|         V |           |     
+     +     +     +-----+
|   5 |   6 |   7     8 | 
|     |     |           |     
+     +-----+-----+     +
|  10    11    12    13 | 
|                       |     
+     +-----+     +     +
|  15 |  16 |  17 |  18 | 
|     |     |     |     |     
+     +     +     +-----+
|  20 |  21    22    23 | 
|     |                 |     
+-----+-----+-----+-----+

* accion: dist:0.09 acel= 1.00 vmax=0.20 vfin=0.20 deceleracion=1.00 pasos_hasta_dec=236 pasos_obj=236 r=99999.00
leds:187	64	46	257	
cambio a casilla 6
Orientacion 2
+-----+-----+-----+-----+
|   0     1 |   2     3 | 
|           |           |     
+     +     +     +-----+
|   5 |   6 |   7     8 | 
|     |   V |           |     
+     +-----+-----+     +
|  10    11    12    13 | 
|                       |     
+     +-----+     +     +
|  15 |  16 |  17 |  18 | 
|     |     |     |     |     
+     +     +     +-----+
|  20 |  21    22    23 | 
|     |                 |     
+-----+-----+-----+-----+

continuo - leds enfrente: 46/64
callejon sin salida - paro para giro 180
* accion: dist:0.09 acel= 1.00 vmax=0.20 vfin=0.10 deceleracion=0.80 pasos_hasta_dec=186 pasos_obj=236 r=99999.00
chocamos! leds:
301/308, pasos objetivo =236 recorridos =137
pausa pregiro
* accion: dist:0.00 acel= 0.00 vmax=0.00 vfin=0.00 deceleracion=0.00 pasos_hasta_dec=-2147483648 pasos_obj=0 r=0.20
leds:237	308	301	232	
giro 180
* accion: dist:0.10 acel= 1.00 vmax=0.20 vfin=0.10 deceleracion=1.00 pasos_hasta_dec=223 pasos_obj=262 r=0.00
pausa inicial
* accion: dist:0.00 acel= 0.00 vmax=0.00 vfin=0.00 deceleracion=0.00 pasos_hasta_dec=-2147483648 pasos_obj=0 r=0.20
Orientacion 0
+-----+-----+-----+-----+
|   0     1 |   2     3 | 
|           |           |     
+     +     +     +-----+
|   5 |   6 |   7     8 | 
|     |   A |           |     
+     +-----+-----+     +
|  10    11    12    13 | 
|                       |     
+     +-----+     +     +
|  15 |  16 |  17 |  18 | 
|     |     |     |     |     
+     +     +     +-----+
|  20 |  21    22    23 | 
|     |                 |     
+-----+-----+-----+-----+

* accion: dist:0.09 acel= 1.00 vmax=0.20 vfin=0.20 deceleracion=1.00 pasos_hasta_dec=236 pasos_obj=236 r=99999.00
leds:0	25	18	166	
cambio a casilla 1
Orientacion 0
+-----+-----+-----+-----+
|   0     1 |   2     3 | 
|         A |           |     
+     +     +     +-----+
|   5 |   6 |   7     8 | 
|     |     |           |     
+     +-----+-----+     +
|  10    11    12    13 | 
|                       |     
+     +-----+     +     +
|  15 |  16 |  17 |  18 | 
|     |     |     |     |     
+     +     +     +-----+
|  20 |  21    22    23 | 
|     |                 |     
+-----+-----+-----+-----+

continuo - leds enfrente: 18/25
paro para giro izquierda
* accion: dist:0.09 acel= 1.00 vmax=0.20 vfin=0.10 deceleracion=0.80 pasos_hasta_dec=186 pasos_obj=236 r=99999.00
chocamos! leds:
287/323, pasos objetivo =236 recorridos =211
pausa pregiro
* accion: dist:0.00 acel= 0.00 vmax=0.00 vfin=0.00 deceleracion=0.00 pasos_hasta_dec=-2147483648 pasos_obj=0 r=0.20
leds:1	323	287	150	
giro izquierda
* accion: dist:0.05 acel= 1.00 vmax=0.20 vfin=0.10 deceleracion=1.00 pasos_hasta_dec=92 pasos_obj=131 r=0.00
pausa inicial
* accion: dist:0.00 acel= 0.00 vmax=0.00 vfin=0.00 deceleracion=0.00 pasos_hasta_dec=-2147483648 pasos_obj=0 r=0.20
Orientacion 3
+-----+-----+-----+-----+
|   0     1 |   2     3 | 
|         < |           |     
+     +     +     +-----+
|   5 |   6 |   7     8 | 
|     |     |           |     
+     +-----+-----+     +
|  10    11    12    13 | 
|                       |     
+     +-----+     +     +
|  15 |  16 |  17 |  18 | 
|     |     |     |     |     
+     +     +     +-----+
|  20 |  21    22    23 | 
|     |                 |     
+-----+-----+-----+-----+

* accion: dist:0.09 acel= 1.00 vmax=0.20 vfin=0.20 deceleracion=1.00 pasos_hasta_dec=236 pasos_obj=236 r=99999.00
leds:-1	31	24	105	
cambio a casilla 0
Orientacion 3
+-----+-----+-----+-----+
|   0     1 |   2     3 | 
|   <       |           |     
+     +     +     +-----+
|   5 |   6 |   7     8 | 
|     |     |           |     
+     +-----+-----+     +
|  10    11    12    13 | 
|                       |     
+     +-----+     +     +
|  15 |  16 |  17 |  18 | 
|     |     |     |     |     
+     +     +     +-----+
|  20 |  21    22    23 | 
|     |                 |     
+-----+-----+-----+-----+

continuo - leds enfrente: 24/31
paro para giro izquierda
* accion: dist:0.09 acel= 1.00 vmax=0.20 vfin=0.10 deceleracion=0.80 pasos_hasta_dec=186 pasos_obj=236 r=99999.00
chocamos! leds:
249/360, pasos objetivo =236 recorridos =174
pausa pregiro
* accion: dist:0.00 acel= 0.00 vmax=0.00 vfin=0.00 deceleracion=0.00 pasos_hasta_dec=-2147483648 pasos_obj=0 r=0.20
leds:0	360	249	127	
giro izquierda
* accion: dist:0.05 acel= 1.00 vmax=0.20 vfin=0.10 deceleracion=1.00 pasos_hasta_dec=92 pasos_obj=131 r=0.00
pausa inicial
* accion: dist:0.00 acel= 0.00 vmax=0.00 vfin=0.00 deceleracion=0.00 pasos_hasta_dec=-2147483648 pasos_obj=0 r=0.20
Orientacion 2
+-----+-----+-----+-----+
|   0     1 |   2     3 | 
|   V       |           |     
+     +     +     +-----+
|   5 |   6 |   7     8 | 
|     |     |           |     
+     +-----+-----+     +
|  10    11    12    13 | 
|                       |     
+     +-----+     +     +
|  15 |  16 |  17 |  18 | 
|     |     |     |     |     
+     +     +     +-----+
|  20 |  21    22    23 | 
|     |                 |     
+-----+-----+-----+-----+

* accion: dist:0.09 acel= 1.00 vmax=0.20 vfin=0.20 deceleracion=1.00 pasos_hasta_dec=236 pasos_obj=236 r=99999.00
leds:290	0	-1	176	
cambio a casilla 5
Orientacion 2
+-----+-----+-----+-----+
|   0     1 |   2     3 | 
|           |           |     
+     +     +     +-----+
|   5 |   6 |   7     8 | 
|   V |     |           |     
+     +-----+-----+     +
|  10    11    12    13 | 
|                       |     
+     +-----+     +     +
|  15 |  16 |  17 |  18 | 
|     |     |     |     |     
+     +     +     +-----+
|  20 |  21    22    23 | 
|     |                 |     
+-----+-----+-----+-----+

continuo - leds enfrente: -1/0
* accion: dist:0.18 acel= 1.00 vmax=0.20 vfin=0.20 deceleracion=1.00 pasos_hasta_dec=472 pasos_obj=472 r=99999.00
sinc pared derecha
leds:0	3	0	140	
cambio a casilla 10
Orientacion 2
+-----+-----+-----+-----+
|   0     1 |   2     3 | 
|           |           |     
+     +     +     +-----+
|   5 |   6 |   7     8 | 
|     |     |           |     
+     +-----+-----+     +
|  10    11    12    13 | 
|   V                   |     
+     +-----+     +     +
|  15 |  16 |  17 |  18 | 
|     |     |     |     |     
+     +     +     +-----+
|  20 |  21    22    23 | 
|     |                 |     
+-----+-----+-----+-----+

continuo - leds enfrente: 0/3
* accion: dist:0.18 acel= 1.00 vmax=0.20 vfin=0.20 deceleracion=1.00 pasos_hasta_dec=472 pasos_obj=472 r=99999.00
leds:239	1	1	198	
cambio a casilla 15
Orientacion 2
+-----+-----+-----+-----+
|   0     1 |   2     3 | 
|           |           |     
+     +     +     +-----+
|   5 |   6 |   7     8 | 
|     |     |           |     
+     +-----+-----+     +
|  10    11    12    13 | 
|                       |     
+     +-----+     +     +
|  15 |  16 |  17 |  18 | 
|   V |     |     |     |     
+     +     +     +-----+
|  20 |  21    22    23 | 
|     |                 |     
+-----+-----+-----+-----+

continuo - leds enfrente: 1/1
* accion: dist:0.18 acel= 1.00 vmax=0.20 vfin=0.20 deceleracion=1.00 pasos_hasta_dec=472 pasos_obj=472 r=99999.00
leds:232	96	66	244	
cambio a casilla 20
Orientacion 2
+-----+-----+-----+-----+
|   0     1 |   2     3 | 
|           |           |     
+     +     +     +-----+
|   5 |   6 |   7     8 | 
|     |     |           |     
+     +-----+-----+     +
|  10    11    12    13 | 
|                       |     
+     +-----+     +     +
|  15 |  16 |  17 |  18 | 
|     |     |     |     |     
+     +     +     +-----+
|  20 |  21    22    23 | 
|   V |                 |     
+-----+-----+-----+-----+

continuo - leds enfrente: 66/96
callejon sin salida - paro para giro 180
* accion: dist:0.09 acel= 1.00 vmax=0.20 vfin=0.10 deceleracion=0.80 pasos_hasta_dec=186 pasos_obj=236 r=99999.00
chocamos! leds:
278/332, pasos objetivo =236 recorridos =96
pausa pregiro
* accion: dist:0.00 acel= 0.00 vmax=0.00 vfin=0.00 deceleracion=0.00 pasos_hasta_dec=-2147483648 pasos_obj=0 r=0.20
leds:254	332	278	219	
giro 180
* accion: dist:0.10 acel= 1.00 vmax=0.20 vfin=0.10 deceleracion=1.00 pasos_hasta_dec=223 pasos_obj=262 r=0.00
pausa inicial
* accion: dist:0.00 acel= 0.00 vmax=0.00 vfin=0.00 deceleracion=0.00 pasos_hasta_dec=-2147483648 pasos_obj=0 r=0.20
Orientacion 0
+-----+-----+-----+-----+
|   0     1 |   2     3 | 
|           |           |     
+     +     +     +-----+
|   5 |   6 |   7     8 | 
|     |     |           |     
+     +-----+-----+     +
|  10    11    12    13 | 
|                       |     
+     +-----+     +     +
|  15 |  16 |  17 |  18 | 
|     |     |     |     |     
+     +     +     +-----+
|  20 |  21    22    23 | 
|   A |                 |     
+-----+-----+-----+-----+

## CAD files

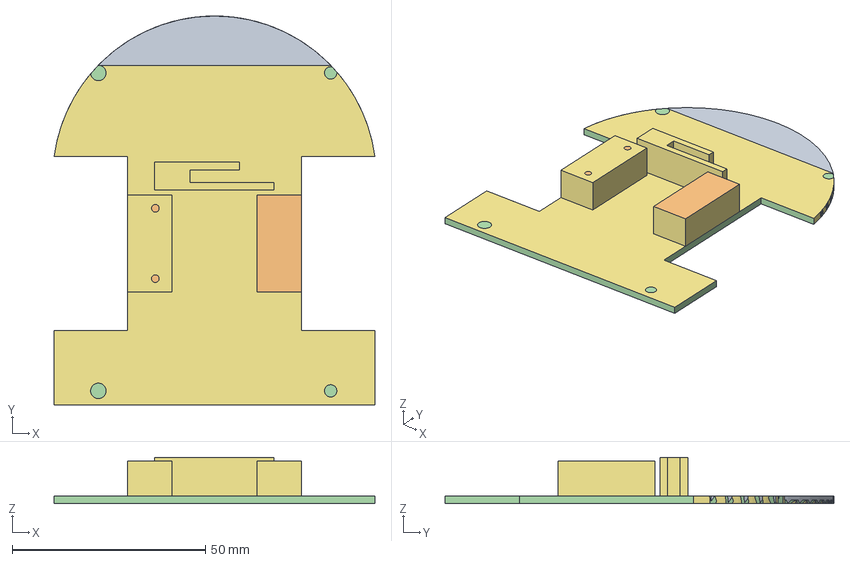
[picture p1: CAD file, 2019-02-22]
3d/adefesio-v0.2/chasis-inferior.fcstd
83.0 x 100.6 x 12.0 mm
base
soporte-motores
pared-bateria
hueco-sensores
taladros
taladros-motor-arriba
taladros-motor-abajo

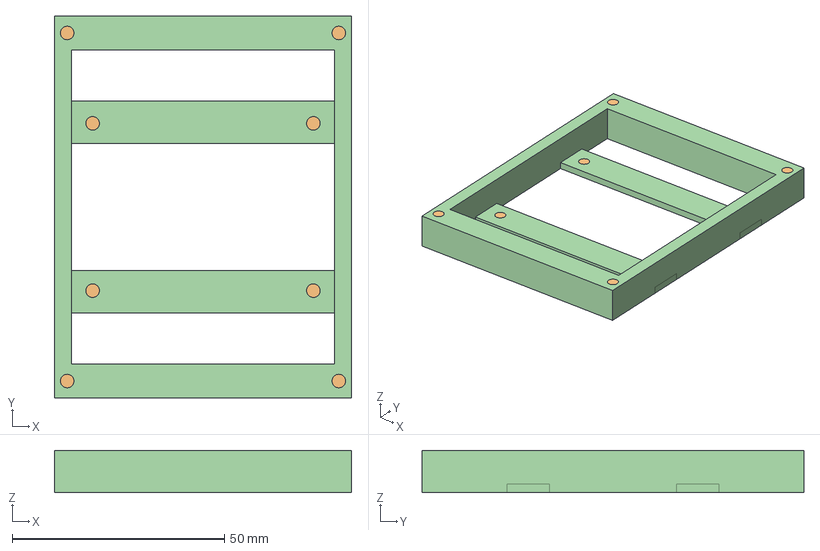
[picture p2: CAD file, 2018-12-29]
3d/baquelita/baquelita-mount.fcstd
70.0 x 90.0 x 10.0 mm
base
crossbars
crossbar-holes
base-holes
frontal-holes

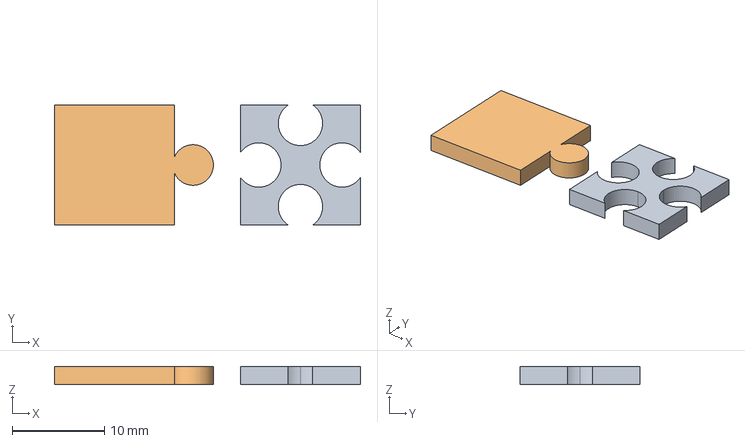
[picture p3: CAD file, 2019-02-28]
3d/misc/encajes-pared-viga-2.fcstd
33.1 x 13.0 x 2.00 mm
encaje-vigueta
encaje-pared

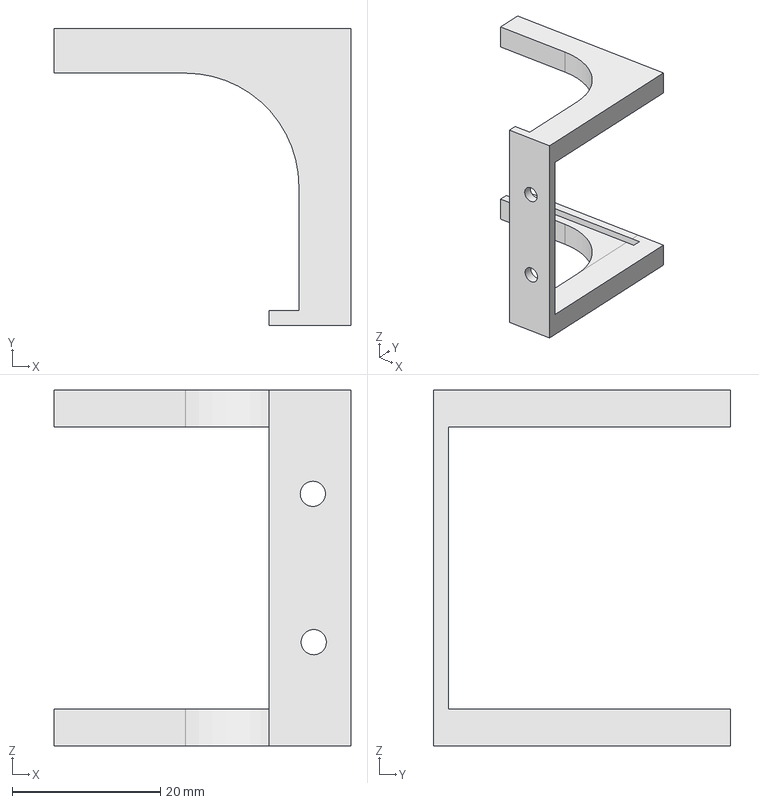
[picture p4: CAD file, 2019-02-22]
3d/adefesio-v0.2/soporte-placa.fcstd
40.0 x 40.0 x 48.0 mm

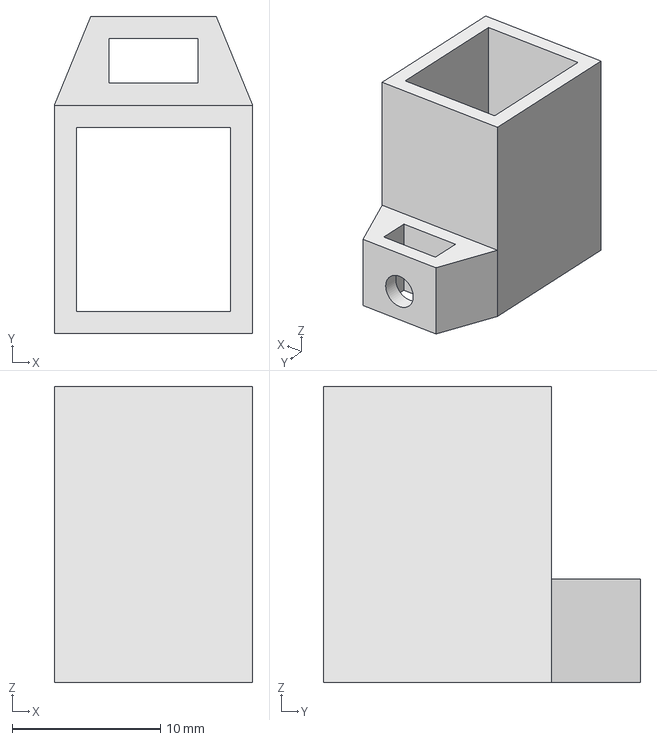
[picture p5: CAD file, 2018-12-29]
3d/baquelita/motormount.fcstd
13.4 x 21.4 x 20.0 mm

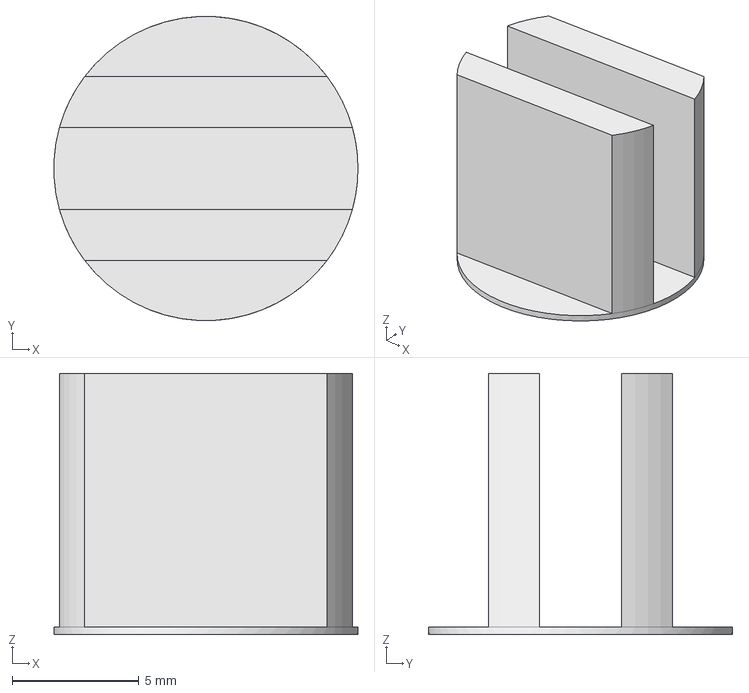
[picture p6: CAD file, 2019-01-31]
3d/misc/soporte-contrachapado-3mm.fcstd
12.0 x 12.0 x 10.3 mm

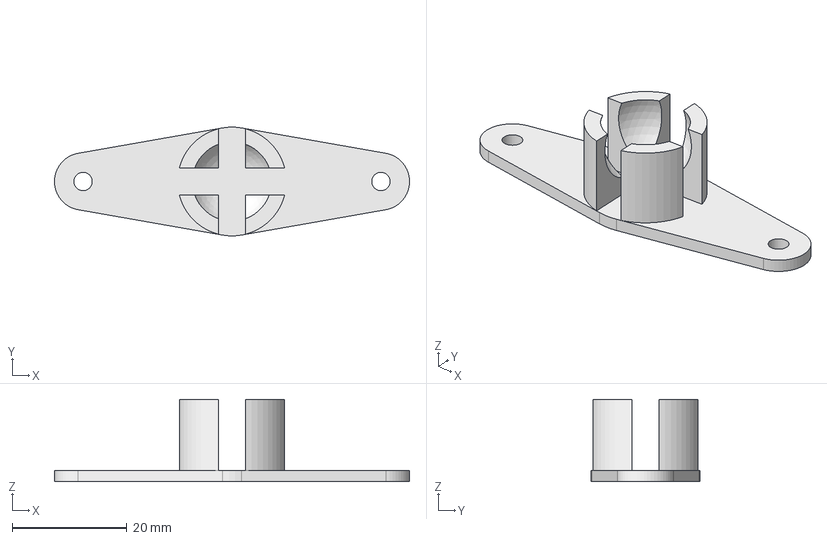
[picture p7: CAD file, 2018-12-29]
3d/baquelita/ballcaster.fcstd
62.0 x 19.0 x 14.4 mm

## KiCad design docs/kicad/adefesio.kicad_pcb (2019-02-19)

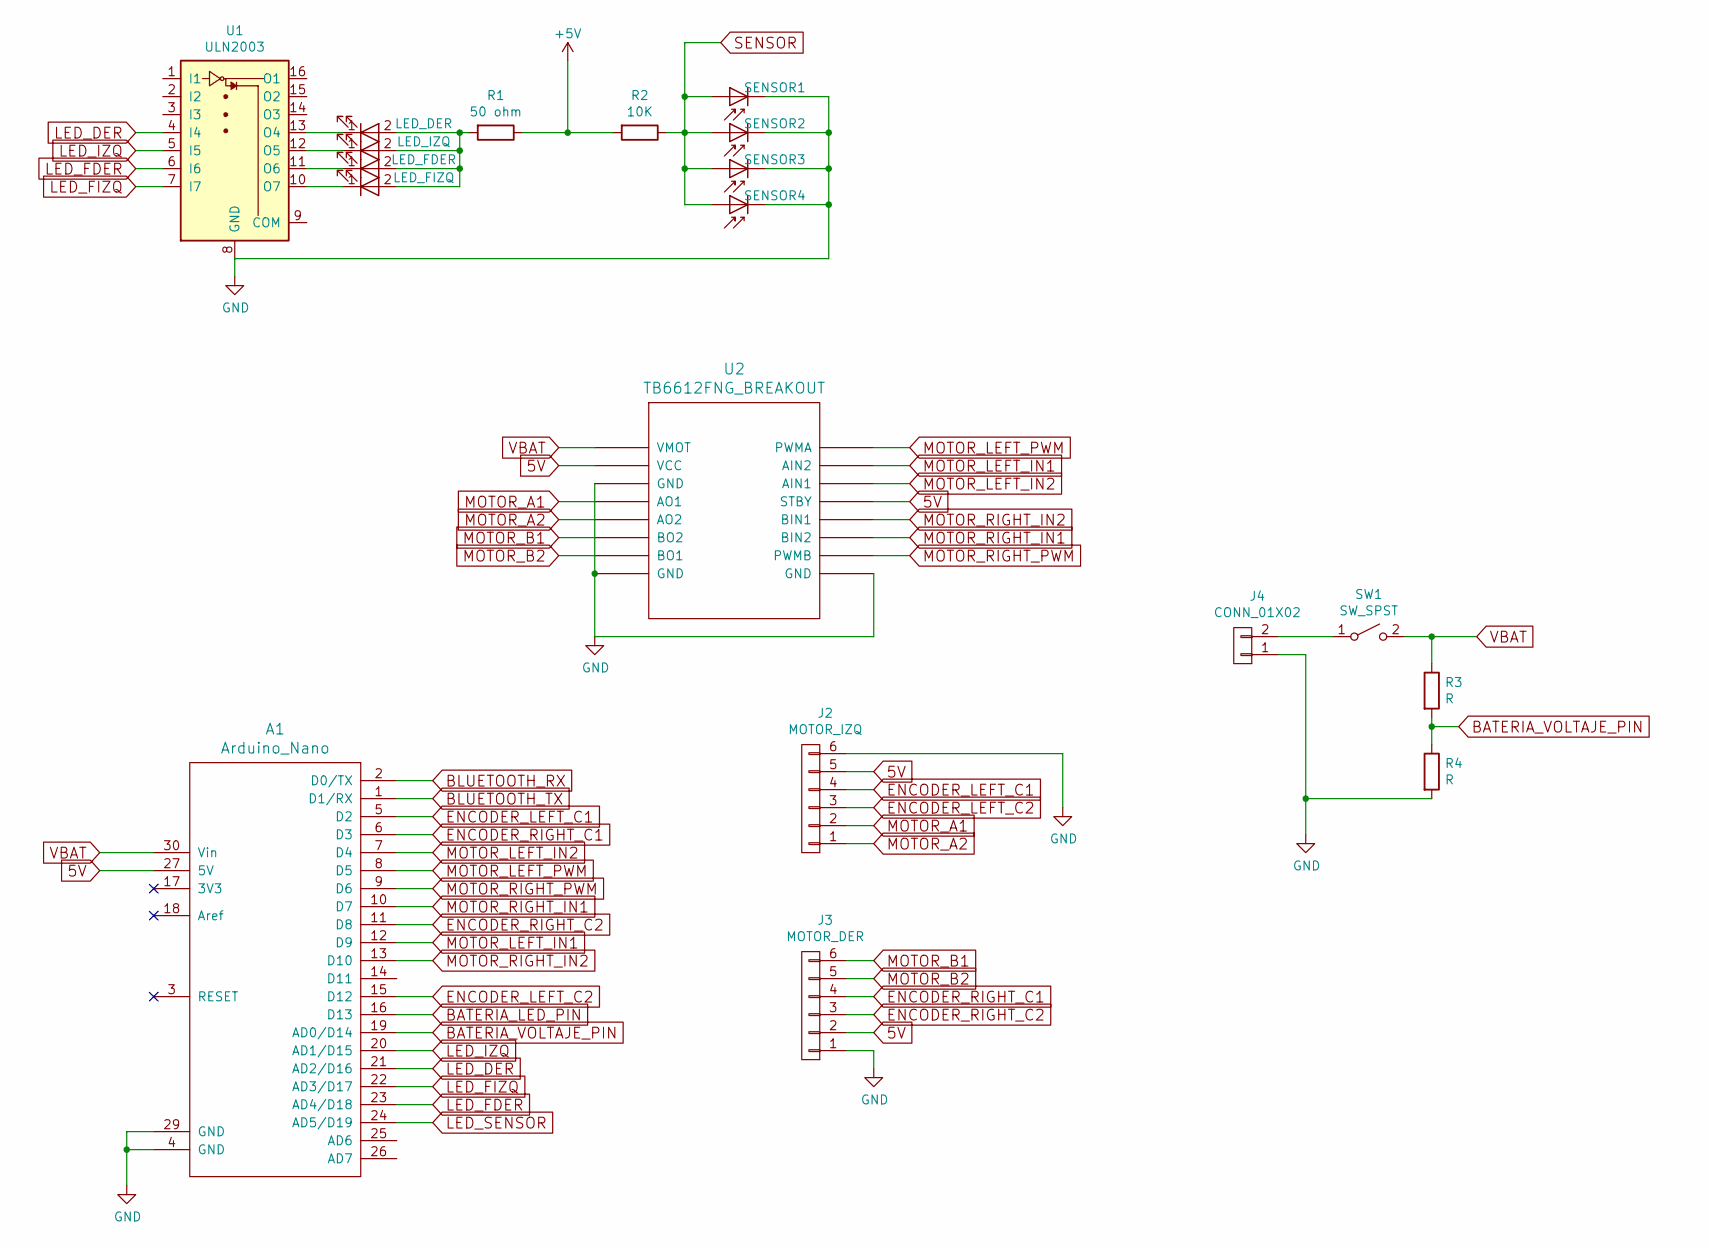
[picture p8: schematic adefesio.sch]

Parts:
A1: Arduino_Nano; arduino_nano
D1: LED_DER; LED_D1.8mm_W1.8mm_H2.4mm_Horizontal_O6.35mm_Z1.6mm
D2: SENSOR1; LED_D1.8mm_W1.8mm_H2.4mm_Horizontal_O3.81mm_Z1.6mm
D3: LED_IZQ; LED_D1.8mm_W1.8mm_H2.4mm_Horizontal_O6.35mm_Z1.6mm
D4: LED_FDER; LED_D1.8mm_W1.8mm_H2.4mm_Horizontal_O6.35mm_Z1.6mm
D5: LED_FIZQ; LED_D1.8mm_W1.8mm_H2.4mm_Horizontal_O6.35mm_Z1.6mm
D6: SENSOR2; LED_D1.8mm_W1.8mm_H2.4mm_Horizontal_O3.81mm_Z1.6mm
D7: SENSOR3; LED_D1.8mm_W1.8mm_H2.4mm_Horizontal_O3.81mm_Z1.6mm
D8: SENSOR4; LED_D1.8mm_W1.8mm_H2.4mm_Horizontal_O3.81mm_Z1.6mm
J2: MOTOR_IZQ; PINHEAD1-6
J3: MOTOR_DER; PINHEAD1-6
J4: CONN_01X02; PINHEAD1-2
R1: 50 ohm; R_Axial_DIN0207_L6.3mm_D2.5mm_P10.16mm_Horizontal
R2: 10K; R_Axial_DIN0207_L6.3mm_D2.5mm_P10.16mm_Horizontal
R3, R4: R; R_Axial_DIN0204_L3.6mm_D1.6mm_P7.62mm_Horizontal
SW1: SW_SPST; SW_DIP_x1_W7.62mm_Slide_Copal_CHS-B
U1: ULN2003; DIP-16_W7.62mm_LongPads
U2: TB6612FNG_BREAKOUT; DIP-16_600

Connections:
5V: A1.27 (5V), J2.5, J3.2, U2.2 (VCC), U2.13 (STBY)
+5V: R1.1, R2.2
BATERIA_LED_PIN: A1.16 (D13)
BATERIA_VOLTAJE_PIN: A1.19 (AD0/D14), R3.2, R4.1
BLUETOOTH_RX: A1.2 (D0/TX)
BLUETOOTH_TX: A1.1 (D1/RX)
ENCODER_LEFT_C1: A1.5 (D2), J2.4
ENCODER_LEFT_C2: A1.15 (D12), J2.3
ENCODER_RIGHT_C1: A1.6 (D3), J3.4
ENCODER_RIGHT_C2: A1.11 (D8), J3.3
GND: A1.4 (GND), A1.29 (GND), D2.1 (K), D6.1 (K), D7.1 (K), D8.1 (K), J2.6, J3.1, J4.1, R4.2, U1.8 (GND), U2.3 (GND), U2.8 (GND), U2.9 (GND)
LED_DER: A1.21 (AD2/D16), U1.4 (I4)
LED_FDER: A1.23 (AD4/D18), U1.6 (I6)
LED_FIZQ: A1.22 (AD3/D17), U1.7 (I7)
LED_IZQ: A1.20 (AD1/D15), U1.5 (I5)
LED_SENSOR: A1.24 (AD5/D19)
MOTOR_A1: J2.2, U2.4 (AO1)
MOTOR_A2: J2.1, U2.5 (AO2)
MOTOR_B1: J3.6, U2.6 (BO2)
MOTOR_B2: J3.5, U2.7 (BO1)
MOTOR_LEFT_IN1: A1.12 (D9), U2.15 (AIN2)
MOTOR_LEFT_IN2: A1.7 (D4), U2.14 (AIN1)
MOTOR_LEFT_PWM: A1.8 (D5), U2.16 (PWMA)
MOTOR_RIGHT_IN1: A1.10 (D7), U2.11 (BIN2)
MOTOR_RIGHT_IN2: A1.13 (D10), U2.12 (BIN1)
MOTOR_RIGHT_PWM: A1.9 (D6), U2.10 (PWMB)
unnamed: D1.1 (K), U1.13 (O4)
unnamed: D1.2 (A), D3.2 (A), D4.2 (A), D5.2 (A), R1.2
unnamed: D3.1 (K), U1.12 (O5)
unnamed: D4.1 (K), U1.11 (O6)
unnamed: D5.1 (K), U1.10 (O7)
unnamed: J4.2, SW1.1 (A)
SENSOR: D2.2 (A), D6.2 (A), D7.2 (A), D8.2 (A), R2.1
VBAT: A1.30 (Vin), R3.1, SW1.2 (B), U2.1 (VMOT)

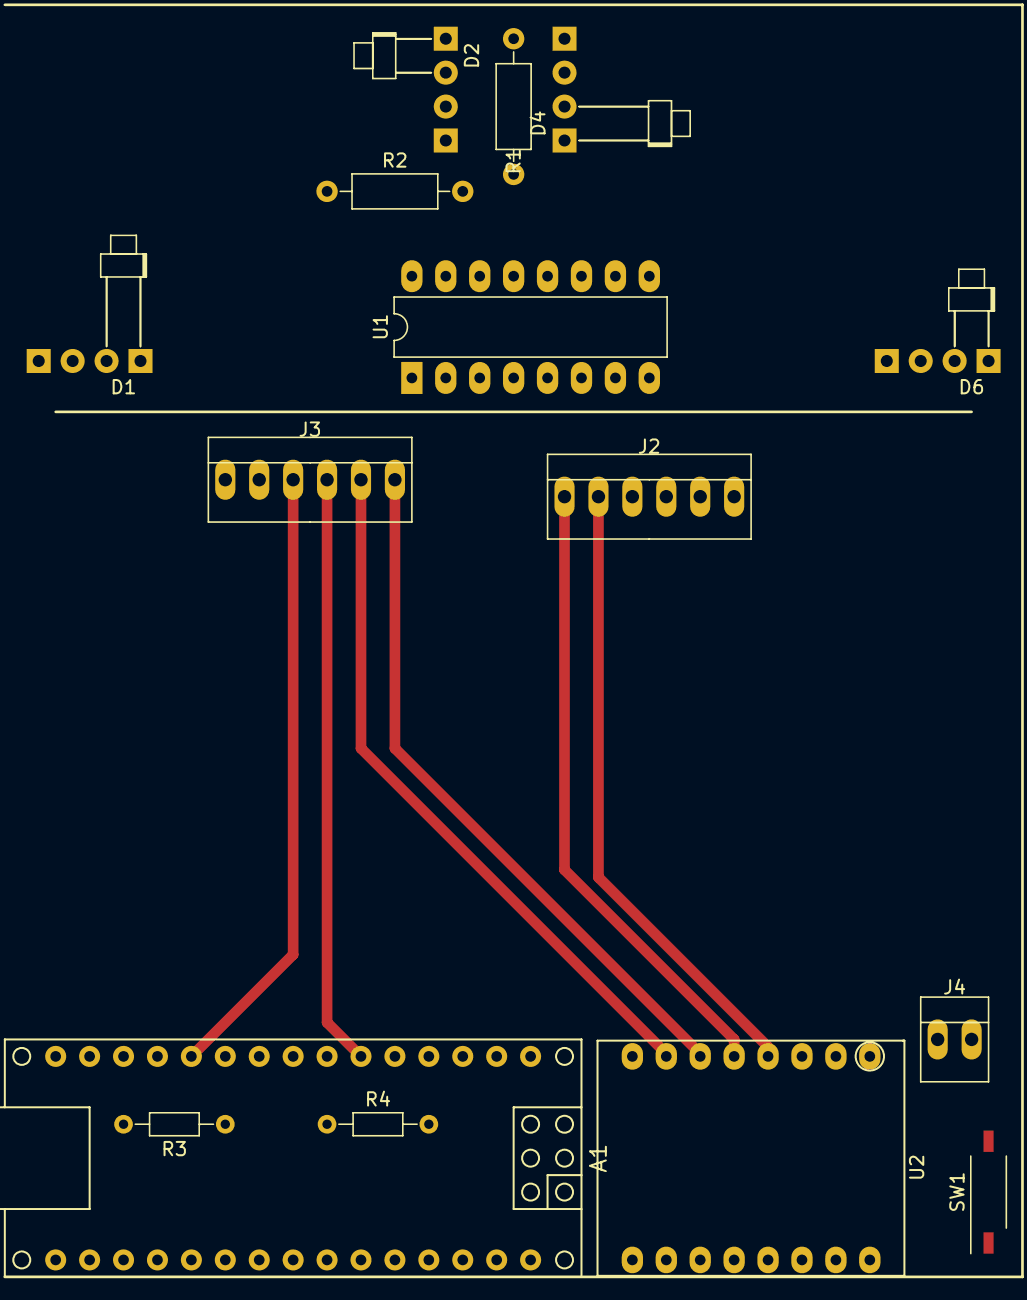
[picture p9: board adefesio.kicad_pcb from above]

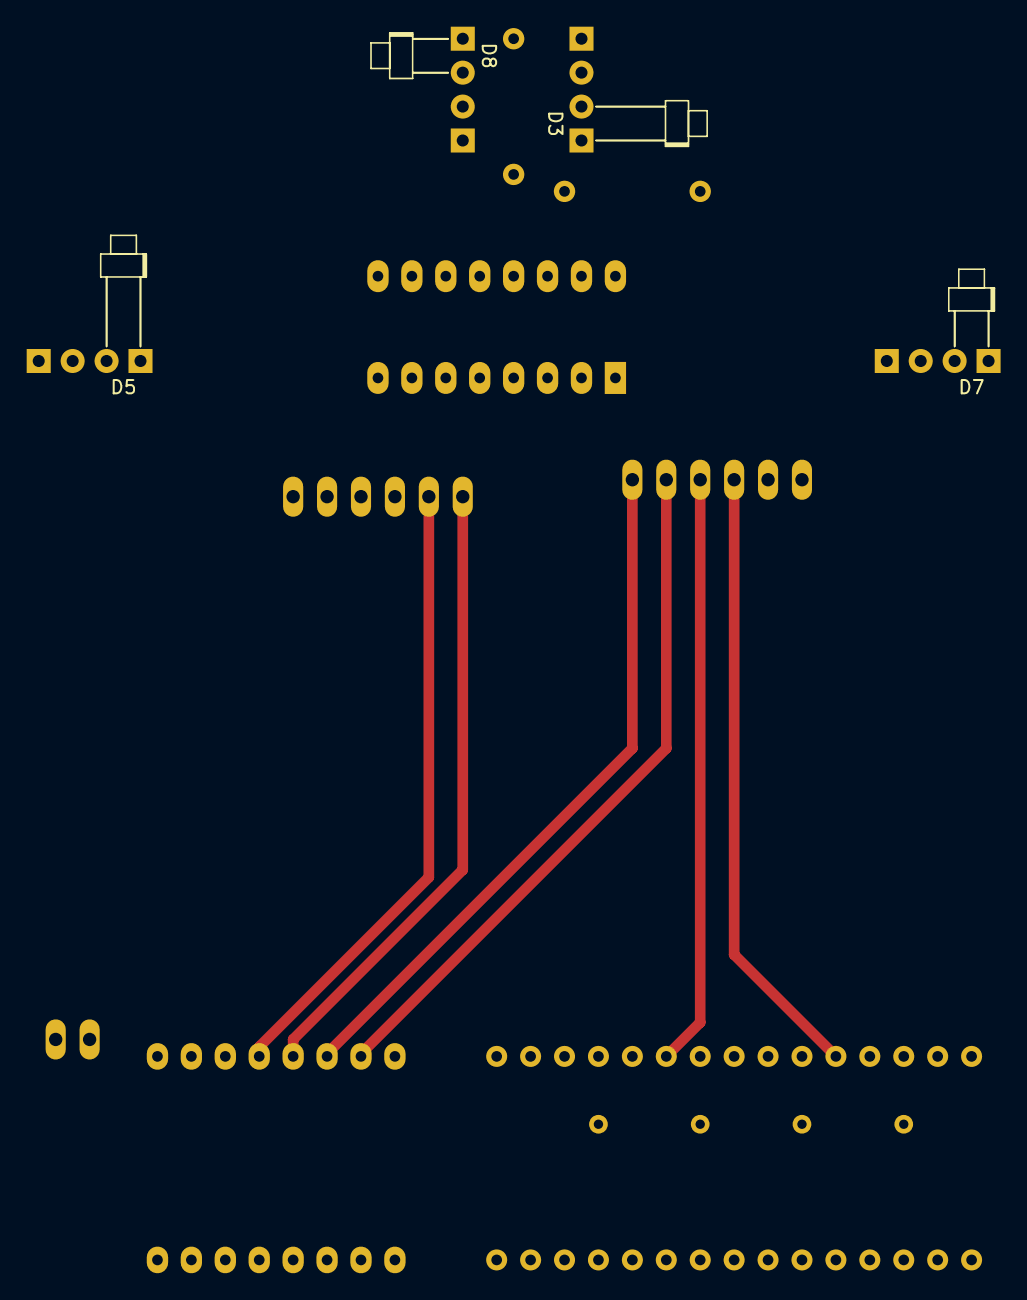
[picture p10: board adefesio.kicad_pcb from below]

Board: 2 copper layers, 19 parts (4 on the bottom side), 30 nets.

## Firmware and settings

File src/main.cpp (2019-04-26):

#include <Arduino.h>
#include <settings.h>
#include <robot.h>
#include <motores.h>
#include <bateria.h>
#include <encoders.h>
#include <timer1.h>
#include <log.h>
#include <comando.h>
#include <robot.h>
#include <leds.h>
#include <laberinto.h>
#include <flood.h>
#include <camino.h>
#include <accion.h>

ISR (TIMER1_COMPA_vect) {

#ifdef MOCK
    robot_control();
#else
    switch (timer1_get_estado()) {
        case 0: 
                leds_actualiza_valor(LED_IZQ);
                break;
        case 1: 
                leds_actualiza_valor(LED_FDER);
                break;
        case 2: 
                leds_actualiza_valor(LED_DER);
                break;
        case 3: 
                leds_actualiza_valor(LED_FIZQ);
                encoders_calcula_velocidad();
                encoders_reset_posicion();
                robot_control();
                motores_actualiza_velocidad();
                break;
    }
#endif
    timer1_incrementa_cuenta();
}


void setup() {

    Serial.begin(115200);
    bateria_init();
    motores_init(bateria_get_voltaje());
    encoders_init();
    leds_init();
    comando_init();
    bateria_muestra_nivel();

    timer1_init(PERIODO_TIMER, 1);
    robot_init();
    laberinto_init();
    laberinto_print();

    pinMode(A5, INPUT_PULLUP);
    pinMode(A6, INPUT_PULLUP);

}

void loop() {

    comando_prompt();

    leds_activa();

    robot_calibracion_frontal();
    leds_calibracion_lateral();

    // test calibracion
    /*j
    while (true) {
        log_leds_distancias();
    }
    */

    robot_init();
    camino_init();


    leds_reset_go();

    while (true) {
#ifdef MOCK
        while (!comando_get_go()) {
#else
        while (!leds_go() and !comando_get_go()) {
#endif

            //log_leds_distancias();
            //Serial.println(leds_get_distancia(LED_FDER) + leds_get_distancia(LED_FIZQ));
            comando_lee_serial();
            //log_leds_distancias();
            delay(100);
            //log_casilla_pasos_leds();
        }
        //Serial.println("inicia Flood");
        //flood_init(CASILLA_SOLUCION);

        bateria_watchdog();
        Serial.println("empiezo");

        robot_empieza();
        //while (robot_get_estado() != ESPERANDO_SENAL) {
        while (true) {
            log_correccion_pasillos();
            //log_leds_distancias();
            log_variables_trayectoria();
#ifdef MOCK
            comando_lee_serial();
#endif
        }
    }

    
}

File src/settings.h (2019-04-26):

/**
 * @file settings.h
 *
 * @brief Variables globales
 */

#ifndef __SETTINGS_H
#define __SETTINGS_H

/// Constante definida para simulador mms
/// #define MOCK 1

//@{
/**
 * @name Características físicas del robot
 */

/// Radio de las ruedas motrices, en metros
#define RADIO_RUEDAS 0.022992

/// Distancia entre las ruedas, en metros
#define DISTANCIA_ENTRE_RUEDAS (0.07)

/// Anchura robot
#define ANCHURA_ROBOT 0.085
#define DISTANCIA_ROBOT_MURO ((LABERINTO_LONGITUD_CASILLA - LABERINTO_ANCHURA_MURO - ANCHURA_ROBOT) / 2.0)
//@}

//@{
/**
 * @name Configuración del encoder
 */
/// Número de saltos del encoder por cada vuelta completa de rueda
#define PASOS_POR_VUELTA 357.7

/// Metros recorridos por cada paso de encoder
#define LONGITUD_PASO_ENCODER ((2 * PI * RADIO_RUEDAS) / PASOS_POR_VUELTA)
//@}

//@{
/**
 * @name Configuración del timer
 */

#ifdef MOCK
#define PERIODO_TIMER 0.005
#else
#define PERIODO_TIMER 0.001
#endif

/// Distintos estados del timer (cada ciclo de timer se ejecuta un estado distinto)
#define NUMERO_ESTADOS 4

/// Periodo de un ciclo (dependiente del periodo del timer y el numero de estados
#define PERIODO_CICLO (PERIODO_TIMER * NUMERO_ESTADOS)

/// Numero total de OCR1A's contando el numero de estados
#define OCR1A_POR_CICLO (OCR1A * NUMERO_ESTADOS)
//@}

//@{
/**
 * @name Constantes de PID
 *
 * @todo Establecer constantes para los demás pid
 */
#define KP_LINEAL -0.6 ///< Constante P por defecto para pid de velocidad lineal
#define KD_LINEAL -0.0 ///< Constante D por defecto para pid de velocidad lineal
#define KI_LINEAL -0.0 ///< Constante I por defecto para pid de velocidad lineal

//#define KP_PASILLO1 45.0 ///< Constante por defecto P para corrección entre pasillos
//#define KP_PASILLO2 4000.0 ///< Constante por defecto D para corrección entre pasillos
#define KP_PASILLO1 50.0 ///< Constante por defecto P para corrección entre pasillos
#define KP_PASILLO2 1000.0 ///< Constante por defecto D para corrección entre pasillos

/// Define la distancia en la que estimamos incorporarnos al centro en trayectorias rectas
#define DISTANCIA_CONVERGENCIA 0.09
//@}

//@{
/**
 * @name Configuración del laberinto
 */
/*
#define LABERINTO_FILAS 15 ///< Número de filas
#define LABERINTO_COLUMNAS 15 ///< Número de columnas
#define CASILLA_INICIAL 224 ///< Número de casilla en la que se posiciona el robot al inicio de la exploración
#define CASILLA_SOLUCION 14
*/
#define LABERINTO_FILAS 16    ///< Número de filas
#define LABERINTO_COLUMNAS 16 ///< Número de columnas
///< Número de casilla en la que se posiciona el robot al inicio de la exploración. Por defecto ultima fila primera columna
#ifdef MOCK
#define CASILLA_INICIAL (LABERINTO_COLUMNAS * (LABERINTO_FILAS - 1))
#define CASILLA_SOLUCION (LABERINTO_COLUMNAS-1)  
#define ORIENTACION_INICIAL NORTE ///< Orientación del robot al inicio de la exploración
#else
#define CASILLA_INICIAL 255
#define CASILLA_SOLUCION 237
#define ORIENTACION_INICIAL OESTE ///< Orientación del robot al inicio de la exploración
#endif
#define LABERINTO_LONGITUD_CASILLA 0.18 //< Longitud en metros de cada casilla
#define LABERINTO_ANCHURA_MURO 0.012    //< Ancho del muro en metros
//@}

//#define NOFLOOD 1
#endif /* ifndef SETTINGS_H

*/

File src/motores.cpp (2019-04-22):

/**
 * @file motores.cpp
 *
 * @brief Control de motores
 */
#include <Arduino.h>
#include <log.h>
#include <settings.h>
#include <motores.h>
#include <leds.h>
#include <robot.h>
#include <timer1.h>

/// Distancia entre las ruedas, en metros
volatile float distancia_entre_ruedas = DISTANCIA_ENTRE_RUEDAS;

volatile float kp_lineal = KP_LINEAL; ///< Parámetro P para pid de velocidad lineal
volatile float kd_lineal = KD_LINEAL; ///< Parámetro D para pid de velocidad lineal
volatile float ki_lineal = KI_LINEAL; ///< Parámetro I para pid de velocidad lineal

volatile float kp_pasillo1 = KP_PASILLO1; ///< Parametro P para corrección entre pasillos en funcion del desvio lateral
volatile float kp_pasillo2 = KP_PASILLO2; ///< Parametro I para corrección entre pasillos en funcion del incremento de desvio
//@{
/// @name Variables para control de pwm

volatile float potencia_left = 0;  ///< Valor entre 0 y 1 proporcinal a la potencia del motor izquierdo
volatile float potencia_right = 0; ///< Valor entre 0 y 1 proporcinal a la potencia del motor derecho

volatile int16_t pwm_left;         ///< Valor pwm proporcionado al motor izquierdo
volatile int16_t pwm_right;        ///< Valor pwm proporcionado al motor derecho
volatile float maximo_pwm = 0;     ///< Máximo pwm aplicable a los motores
//@}

//@{
/// @name Velocidades y aceleraciones 
volatile float velocidad_lineal_objetivo = 0;
volatile float velocidad_lineal_objetivo_left = 0;
volatile float velocidad_lineal_objetivo_right = 0;

volatile float velocidad_lineal_actual = 0;
volatile float velocidad_lineal_actual_left = 0;
volatile float velocidad_lineal_actual_right = 0;

volatile float aceleracion_lineal = 0.0;
volatile float velocidad_angular_objetivo = 0;
//@}

/// Rado de giro
volatile float radio = 99999; // evita division por 0 en el init


//@{
/// @name Variables para pid
volatile float error_lineal_left = 0;
volatile float error_lineal_right = 0;

volatile float error_acumulado_left = 0;
volatile float error_acumulado_right = 0;

volatile float angulo = 0;
//@}


//@{
/// @name setters y getters
float motores_get_kp_lineal()  { return kp_lineal; }
void motores_set_kp_lineal(float kp) { kp_lineal = kp; }

float motores_get_ki_lineal()  { return ki_lineal; }
void motores_set_ki_lineal(float ki) { ki_lineal = ki; }

float motores_get_kd_lineal()  { return kd_lineal; }
void motores_set_kd_lineal(float kd) { kd_lineal = kd; }

float motores_get_kp_pasillo1()  { return kp_pasillo1; }
void motores_set_kp_pasillo1(float kp) { kp_pasillo1 = kp; }

float motores_get_kp_pasillo2()  { return kp_pasillo2; }
void motores_set_kp_pasillo2(float kp) { kp_pasillo2 = kp; }

float motores_get_velocidad_lineal_objetivo() {
    return velocidad_lineal_objetivo;
}
float motores_get_radio() {
    return radio;
}
void motores_set_velocidad_lineal_objetivo(float velocidad) {
    velocidad_lineal_objetivo = velocidad;
}
float motores_get_velocidad_lineal_objetivo_left() {
    return velocidad_lineal_objetivo_left;
}
float motores_get_velocidad_lineal_objetivo_right() {
    return velocidad_lineal_objetivo_right;
}

int16_t motores_get_pwm_left() { return pwm_left; }
int16_t motores_get_pwm_right() { return pwm_right; }

void motores_set_maximo_pwm(int16_t pwm) {
    if (pwm > 255) pwm = 255;
    maximo_pwm = pwm;
}

float motores_get_velocidad_angular_objetivo() {
    return velocidad_angular_objetivo;
}

float motores_get_distancia_entre_ruedas() {
    return distancia_entre_ruedas;
}

void motores_set_distancia_entre_ruedas(float dr) {
    distancia_entre_ruedas = dr;
}

float motores_get_aceleracion_lineal() {
    return aceleracion_lineal;
}
void motores_set_aceleracion_lineal(float aceleracion) {
    aceleracion_lineal = aceleracion;
}

void motores_set_radio(float r) {
    radio = r;
}
//@}

/**
 * @brief Inicializa pines para el control de motor
 *
 * @param voltaje Voltaje proporcionado por la batería
 *
 * Define los pines digitales IN1 e IN2 para cada motor, que controlan la dirección
 * en la que giran, y los pines PWM y se establece el máximo pwm que se puede
 * aplicar a los motores en función de la carga de la batería.
 *
 * @see https://recunchomaker.github.io/adefesio//motores-y-puente-h/
 * @see https://recunchomaker.github.io/adefesio/normalizar-pwm-en-funcion-bateria/
 */
void motores_init(float voltaje) {

    pinMode(MOTOR_LEFT_IN1, OUTPUT);
    pinMode(MOTOR_LEFT_IN2, OUTPUT);
    pinMode(MOTOR_LEFT_PWM, OUTPUT);
    pinMode(MOTOR_RIGHT_IN1, OUTPUT);
    pinMode(MOTOR_RIGHT_IN2, OUTPUT);
    pinMode(MOTOR_RIGHT_PWM, OUTPUT);

    motores_set_maximo_pwm((int16_t) (255.0 * 6.0 / voltaje));

    motores_set_potencia(0,0);
}


/**
 * @brief Establece un pwm en cada motor con valores normalizados entre 0 y 1
 *
 * @param left Potencia a entregar al motor izquierdo
 * @param right Potencia a entregar al motor derecho
 */

void motores_set_potencia(float left, float right) {
    if (left > 1) left = 1;
    if (right > 1) right = 1;
    if (left < -1) left = -1;
    if (right < -1) right = -1;

    motores_set_pwm_left((int16_t) (left * maximo_pwm));
    motores_set_pwm_right((int16_t) (right * maximo_pwm));
    potencia_left = left;
    potencia_right = right;
    encoders_set_direccion(potencia_left > 0, potencia_right > 0);
}


/**
 * @brief Estabece el pwm del motor derecho
 *
 * @param right Valor de pwm entre -255 y 255
 *
 * Se configuran los pines IN1 e IN2 en función del sentido de giro
 * y se escribe el valor absoluto del parámetro en el pin de pwm
 */
void motores_set_pwm_right(int16_t right) {
    if (right > 0) {
        if (right > maximo_pwm) right = maximo_pwm;
        digitalWrite(MOTOR_RIGHT_IN1, HIGH);
        digitalWrite(MOTOR_RIGHT_IN2, LOW);
        analogWrite(MOTOR_RIGHT_PWM, right);
        pwm_right = right;
    } else {
        if (right < -maximo_pwm) right = -maximo_pwm;
        digitalWrite(MOTOR_RIGHT_IN1, LOW);
        digitalWrite(MOTOR_RIGHT_IN2, HIGH);
        analogWrite(MOTOR_RIGHT_PWM, -right);
        pwm_right = right;
    }
}


/**
 * @brief Estabece el pwm del motor izquierdo 
 *
 * @param right Valor de pwm entre -255 y 255
 *
 * Se configuran los pines IN1 e IN2 en función del sentido de giro
 * y se escribe el valor absoluto del parámetro en el pin de pwm
 */
void motores_set_pwm_left(int16_t left) {

    if (left > 0) {
        if (left > maximo_pwm) left = maximo_pwm;
        digitalWrite(MOTOR_LEFT_IN1, HIGH);
        digitalWrite(MOTOR_LEFT_IN2, LOW);
        analogWrite(MOTOR_LEFT_PWM, left);
        pwm_left = left;
    } else {
        if (left < -maximo_pwm) left = -maximo_pwm;
        digitalWrite(MOTOR_LEFT_IN1, LOW);
        digitalWrite(MOTOR_LEFT_IN2, HIGH);
        analogWrite(MOTOR_LEFT_PWM, -left);
        pwm_left = left;
    }
}


/**
 * @brief Resetea velocidades y aceleraciones y para los motores
 */
void motores_parar() {
    aceleracion_lineal = 0;
    velocidad_lineal_objetivo = 0;
    motores_set_potencia(0,0);
    encoders_reset_posicion_total();
}
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

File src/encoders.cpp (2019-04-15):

/**
 * @file encoders.cpp
 *
 * @brief Funciones para controlar los encoders del motor
 */

#include <encoders.h>
#include <motores.h>
#include <settings.h>
#include <timer1.h>

enum tipo_direccion {ENCODER_ATRAS, ENCODER_ADELANTE};

//@{
/** @name Variables contadoras de saltos de encoder
 *
 * Se utilizan varios contadores para cada encoder.
 *
 * encoder_posicion es un contador parcial para cálculos cada interrupcion
 * encoder_psocion_total es un contador parcial para cálculos de acciones
 * encoder_posicion_aux_left es un contador parcial para cálculos en rectas largas que pueden incluir más de una acción
 * alto nivel
 */

volatile int16_t encoder_posicion_left = 0;
volatile int16_t encoder_posicion_right = 0;

volatile int32_t encoder_posicion_total_left = 0;
volatile int32_t encoder_posicion_total_right = 0;

volatile int32_t encoder_posicion_aux_left = 0;
volatile int32_t encoder_posicion_aux_right = 0;
//@}


//@{
/** @name Acumulan los ciclos de reloj en los que no hay información nueva de los encoders
 */
volatile uint8_t ticks_sin_actualizar_left = 0;
volatile uint8_t ticks_sin_actualizar_right = 0;
//@}


//@{
/** @name Guardan los últimos valores del registro TCNT1 en el momento de saltar la ISR de encoder
 */
volatile uint16_t tcnt1_anterior_left = 0;
volatile uint16_t ultimo_tcnt1_left = 0;

volatile uint16_t tcnt1_anterior_right = 0;
volatile uint16_t ultimo_tcnt1_right = 0;
//@}

//@{
/** @name Almacenan las velocidades calculadas del encoder
 */
volatile float velocidad_left = 0;
volatile float velocidad_right = 0;
//@}

//@{
/** @name Almacenan ultima velocidad de cada encoder. Se usa cuando no hay información nueva (ticks_sin_actualizar > 1)
 */
volatile float ultima_velocidad_left = 0;
volatile float ultima_velocidad_right = 0;
//@}

//@{
/** @name Dirección en la que están girando las ruedas
 *
 * No se utiliza la segunda entrada de encoder debido a que puede pasar mucho tiempo desde que activa la ISR hasta que
 * efectivamente se ejectua, estando la segunda entrada en un valor que no se corresponden con el momento del salto
 */

volatile bool direccion_left = ENCODER_ADELANTE;
volatile bool direccion_right = ENCODER_ADELANTE;
//@}


/**
 * @brief Inicializa pins, interrupciones y resetea variables
 */

void encoders_init(void) {

    // pin modes
    pinMode(ENCODER_LEFT_C1, INPUT);
    pinMode(ENCODER_LEFT_C2, INPUT);
    pinMode(ENCODER_RIGHT_C1, INPUT);
    pinMode(ENCODER_RIGHT_C2, INPUT);

    // inicialir interrupciones
    attachInterrupt(
            digitalPinToInterrupt(ENCODER_LEFT_C1),
            encoders_ISR_left, RISING);
    attachInterrupt(
            digitalPinToInterrupt(ENCODER_RIGHT_C1),
            encoders_ISR_right, RISING);

    encoders_reset_posicion();
    encoders_reset_posicion_total();

}


//@{
/// @name setters y getters
int32_t encoders_get_posicion_total_left(void) {
    return encoder_posicion_total_left;
}

int32_t encoders_get_posicion_total_right(void) {
    return encoder_posicion_total_right;
}

int32_t encoders_get_posicion_aux_left(void) {
    return encoder_posicion_aux_left;
}

int32_t encoders_get_posicion_aux_right(void) {
    return encoder_posicion_aux_right;
}

uint8_t encoders_get_ticks_sin_actualizar_left(void) {
    return ticks_sin_actualizar_left;
}

uint8_t encoders_get_ticks_sin_actualizar_right(void) {
    return ticks_sin_actualizar_right;
}

uint16_t encoders_get_tcnt1_anterior_right() {
    return tcnt1_anterior_right;
}

uint16_t encoders_get_ultimo_tcnt1_right() {
    return ultimo_tcnt1_right;
}

float encoders_get_velocidad_left() {
    return velocidad_left;
}

float encoders_get_velocidad_right() {
    return velocidad_right;
}

float encoders_get_ultima_velocidad_left() {
    return ultima_velocidad_left;
}

float encoders_get_ultima_velocidad_right() {
    return ultima_velocidad_right;
}

//@}


/**
 * @brief Resetea el contador parcial
 */
void encoders_reset_posicion(void) {
    encoder_posicion_left = 0;
    encoder_posicion_right = 0;
}

/**
 * @brief Resetea el contador total
 */
void encoders_reset_posicion_total(void) {
    encoder_posicion_total_left = 0;
    encoder_posicion_total_right = 0;
}

/**
 * @brief Resetea el contador total auxiliar
 */
void encoders_reset_posicion_aux_total(void) {
    encoder_posicion_aux_left = 0;
    encoder_posicion_aux_right = 0;
}

/**
 * @brief Calcula la distancia recorrida desde el último reset de las posiciones totales
 */
int32_t encoders_get_posicion_total(void) {
    return (encoder_posicion_total_right + encoder_posicion_total_left) / 2;
}

/**
 * @brief Calcula la distancia recorrida desde el último reset de las posiciones totales
 */
int32_t encoders_get_posicion_aux(void) {
    return (encoder_posicion_aux_right + encoder_posicion_aux_left) / 2;
}

/**
 * @brief Establece la dirección de cada rueda, para saber si sumar o restar en la ISR
 */
void encoders_set_direccion(bool left, bool right) {
    direccion_left = left;
    direccion_right = right;
}

/**
 * @brief Decrementa la posición de ambos encoders un número de pasos
 *
 * @param pasos
 */
void encoders_decrementa_posicion_total(int16_t pasos) {
    encoder_posicion_total_left -= pasos;
    encoder_posicion_total_right -= pasos;
}

/**
 * @brief ISR del encoder izquierdo
 *
 * Se actualizan los contadores respectivos y se guarda el momento (TNCT1) el salto
 */
void encoders_ISR_left(void) {

    ultimo_tcnt1_left = OCR1A * timer1_get_estado() + TCNT1;

    if (direccion_left)
    {
        encoder_posicion_left++;
        encoder_posicion_total_left++;
        encoder_posicion_aux_left++;
    }
    
    else
    {
        encoder_posicion_left--;
        encoder_posicion_total_left--;
        encoder_posicion_aux_left--;
    }
}


/**
 * @brief ISR del encoder izquierdo
 *
 * Se actualizan los contadores respectivos y se guarda el momento (TNCT1) el salto
 */
void encoders_ISR_right(void) {

    ultimo_tcnt1_right = OCR1A * timer1_get_estado() + TCNT1;

    if (direccion_right)
    {
        encoder_posicion_right++;
        encoder_posicion_total_right++;
        encoder_posicion_aux_right++;
    }
    else {
        encoder_posicion_right--;
        encoder_posicion_total_right--;
        encoder_posicion_aux_right--;
    }
}
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

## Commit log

2018-12-27 blog 2018-12-27 Preparando el entorno con platform.io
2018-12-28 anadido control de pwm
2018-12-28 blog 2018-12-28 Motores y puente H
2018-12-29 blog 2018-12-29 LiPo y Chasis
    [ballcaster.fcstd, baquelita-mount.fcstd, motormount.fcstd]
2018-12-30 2018-12-30 Control de bateria
2019-01-02 2018-12-02 Control de los encoders
2019-01-03 2019-01-03 Timers en Atmega328p
2019-01-04 2019-01-04 Controlando la velocidad
2019-01-05 2019-01-05 Controlando la velocidad - caso 1
2019-01-06 2019-01-06 Controlando la velocidad - caso 2
2019-01-07 2019-01-06 Controlando la velicidad - caso 3
2019-01-08 2019-01-08 PID basico
2019-01-11 2019-01-11 Introduciendo velocidad angular
2019-01-14 2019-01-12 Principios de aceleracion
2019-01-17 2019-01-16 Revisitando velocidad
2019-01-17 2019-01-17 Constante KA en pid
2019-01-19 2019-01-19 Revisitando velocidad angular
2019-01-23 2019-01-23 Logeando PID en tiempo real
2019-01-24 2019-01-24 Afinando el pid
2019-01-25 2019-01-25 Calibrando pwm segun bateria
2019-01-26 2019-01-26 Interprete de comandos sencillo
2019-01-28 2019-01-28 Velocidad maxima y de nuevo aceleracion
2019-01-31 2019-01-31 Unas paredes de contrachapado
    [soporte-contrachapado-3mm.fcstd]
2019-02-02 2019-02-02 Velocidad maxima de giro
2019-02-03 2019-02-03 Control de aceleraciones en el timer
    [calculos_varios.ods]
2019-02-05 2018-02-05 Depurando trayectorias
    [calculos_varios.ods]
2019-02-06 2019-02-06 Error en el calculo de sentido
    [calculos_varios.ods]
2019-02-08 2019-02-08 Bugs en robot.cpp
    [comando.cpp, main.cpp, motores.cpp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]
2019-02-09 2019-02-09 Ultimo retoque a la trayectoria
    [calculos_varios.ods]
2019-02-10 2019-02-10 Terminamos con los motores
2019-02-13 2019-02-12 Repartiendo el trabajo
2019-02-14 2019-02-13 Leyendo el sensor
2019-02-15 2019-02-15 Compartir pin de lectura
2019-02-16 2019-02-16 Modulo de sensores en kicad
    [adefesio.kicad_pcb, adefesio.sch]
2019-02-18 2019-18-02 Chasis para sensores
    [chasis-inferior.fcstd]
2019-02-19 2019-02-19 Procastinando
    [adefesio.kicad_pcb, adefesio.sch, chasis-inferior.fcstd]
2019-02-22 2019-02-22 Ultima pieza
    [chasis-inferior.fcstd, soporte-placa.fcstd]
2019-02-24 2019-02-24 Ajustando posicion de sensores
2019-02-26 2019-02-26 Guardando el laberinto
2019-02-28 2019-02-28 Encaje de viguetas y paredes
    [encajes-pared-viga-2.fcstd]
2019-03-01 2019-03-01 Ruido en sensores
2019-03-02 2019-03-02 No hay ruido en los sensores
2019-03-05 2019-03-05 Errores varios
    [calculos_varios.ods]
2019-03-06 2019-03-06 Mano derecha 1 de ...
2019-03-07 Mano derecha 2 de ...
2019-03-08 2019-03-08 Mano derecha 3 de 3 y mapeando correctamente
    [laberinto.cpp, log.cpp, main.cpp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]
2019-03-11 2019-03-11 Continua la documentacion
2019-03-14 Documentando motores y encoders
2019-03-16 2019-03-16 Log enorme de sensores
2019-03-19 Problema grave en sensores
    [extrae_acciones_log.py, leds.cpp, log.cpp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]
2019-03-20 2019-03-20 pid entre paredes
2019-03-22 2019-03-22 y la volvemos a poner
2019-03-25 2019-03-25 Valor medio en leds
2019-03-26 2019-03-26 Calcular la distancia con los sensores
2019-03-27 Valores de led en segmentos
2019-03-28 2019-03-28 Recuperar la linea central - 1
2019-03-29 2019-03-29 intantando correccion angulo - broken
    [camino.cpp, laberinto.cpp, leds.cpp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]
2019-03-30 2019-03-29 Recuperar la linea central -2
2019-03-31 2019-03-31 Minima distancia en leds
2019-04-05 pre arduino day
2019-04-08 limpieza de logs y eliminacion de control en giros
2019-04-09 mejor calculo de camino
2019-04-10 empezando mock para mms
2019-04-13 anadido log para desvio en pasillos
2019-04-17 refactorizando funciones de control a fichero propio
2019-04-22 tunning distancias para calibracion en pasillos
2019-04-22 extraer de robot.cpp el control en avance
2019-04-22 sincronizacion de final de casilla con fin o principio de pared
2019-04-26 arreglado flood despues de romperlo con funciones de control
    [comando.cpp, control.cpp, flood.cpp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]
